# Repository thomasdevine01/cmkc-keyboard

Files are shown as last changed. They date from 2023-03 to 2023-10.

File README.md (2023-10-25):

# Chico State Mechanical Keyboard Club

<p align = "center">
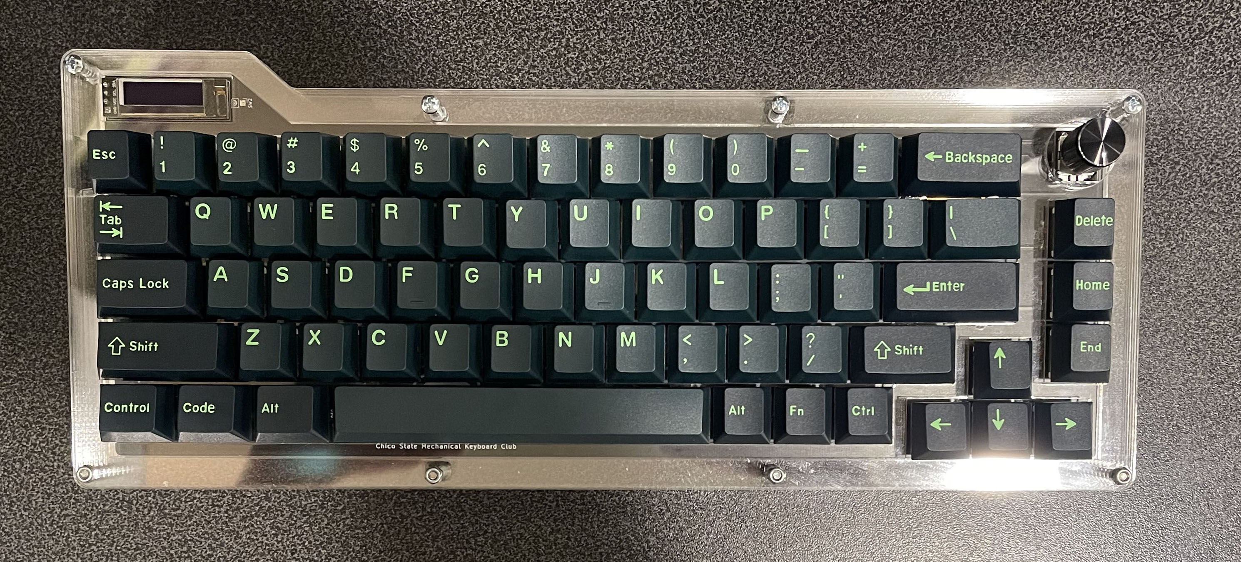
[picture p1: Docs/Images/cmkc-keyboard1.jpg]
    
</p>

<p align = "center">
    A 65% keyboard that features a rotary encoder, OLED Screen and Programmable Firmware.
</p>

## [Installation Guide](Docs/)
  
  1. [Foreword](https://github.com/thomasdevine01/cmkc-keyboard/blob/main/Docs/README.md#foreword)
  2. [Required Parts](https://github.com/thomasdevine01/cmkc-keyboard/blob/main/Docs/README.md#required-parts)
  3. [Optional parts](https://github.com/thomasdevine01/cmkc-keyboard/blob/main/Docs/README.md#optional-parts)
  4. [Tools](https://github.com/thomasdevine01/cmkc-keyboard/blob/main/Docs/README.md#tools)
  5. [Minimum requirements](https://github.com/thomasdevine01/cmkc-keyboard/blob/main/Docs/README.md#minimum-requirements)
  6. [Quality of Life Improvements](https://github.com/thomasdevine01/cmkc-keyboard/blob/main/Docs/README.md#quality-of-life-improvements)
  7. [PCBs: Quick Review](https://github.com/thomasdevine01/cmkc-keyboard/blob/main/Docs/README.md#pcbs-quick-review)
  8. [Soldering: Quick Review](https://github.com/thomasdevine01/cmkc-keyboard/blob/main/Docs/README.md#soldering-quick-review)
  9. [Soldering Tips](https://github.com/thomasdevine01/cmkc-keyboard/blob/main/Docs/README.md#soldering-tips)
  10. [PCB Assembly Tasks](https://github.com/thomasdevine01/cmkc-keyboard/blob/main/Docs/README.md#pcb-assembly-tasks)
  11. [Diodes](https://github.com/thomasdevine01/cmkc-keyboard/blob/main/Docs/README.md#diodes)
  12. [uC Socket](https://github.com/thomasdevine01/cmkc-keyboard/blob/main/Docs/README.md#uc-socket)
  13. [Hardware Fix - Tying Pin 9 to Pin 4](https://github.com/thomasdevine01/cmkc-keyboard/blob/main/Docs/README.md#hardware-fix---tying-pin-9-to-pin-4)
  14. [Recommended Fix - Top Layer](https://github.com/thomasdevine01/cmkc-keyboard/blob/main/Docs/README.md#recommended-fix---top-layer)
  15. [How I did it - Bottom layer underneath socket](https://github.com/thomasdevine01/cmkc-keyboard/blob/main/Docs/README.md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)
  16. [uC header pins](https://github.com/thomasdevine01/cmkc-keyboard/blob/main/Docs/README.md#uc-header-pins)
  17. [Stabilizers](https://github.com/thomasdevine01/cmkc-keyboard/blob/main/Docs/README.md#stabilizers)
  18. [Assembling Stabilizers](https://github.com/thomasdevine01/cmkc-keyboard/blob/main/Docs/README.md#assembling-stabilizers)
  19. [Switches](https://github.com/thomasdevine01/cmkc-keyboard/blob/main/Docs/README.md#switches)
  20. [OLED](https://github.com/thomasdevine01/cmkc-keyboard/blob/main/Docs/README.md#oled)
  21. [Demultiplexer](https://github.com/thomasdevine01/cmkc-keyboard/blob/main/Docs/README.md#demultiplexer)
  22. [Rotary Encoder](https://github.com/thomasdevine01/cmkc-keyboard/blob/main/Docs/README.md#rotary-encoder)
  23. [Soldering Sanity Check](https://github.com/thomasdevine01/cmkc-keyboard/blob/main/Docs/README.md#soldering-sanity-check)
  
## [Photo Gallery](Docs/Images)
## [Parts](Docs/)
### Credits

- Circuit-Dude
- Thomas Devine 

### [Sources](Docs/Sources/)

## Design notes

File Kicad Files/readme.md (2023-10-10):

These are the Schematic and PCB Layout files for the CMKC-65% keyboard.

The current board revision is the -R1.

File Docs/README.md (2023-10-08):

## CMKC PCB Assembly Guide

### Table of Contents
- If you want to use the Table of Contents for navigating the document - click the hambuger menu on the right hand side
1. [Foreword](https://github.com/thomasdevine01/cmkc-keyboard/blob/main/Docs/README.md#foreword)
2. [Required Parts](https://github.com/thomasdevine01/cmkc-keyboard/blob/main/Docs/README.md#required-parts)
3. [Optional parts](https://github.com/thomasdevine01/cmkc-keyboard/blob/main/Docs/README.md#optional-parts)
4. [Tools](https://github.com/thomasdevine01/cmkc-keyboard/blob/main/Docs/README.md#tools)
5. [Minimum requirements](https://github.com/thomasdevine01/cmkc-keyboard/blob/main/Docs/README.md#minimum-requirements)
6. [Quality of Life Improvements](https://github.com/thomasdevine01/cmkc-keyboard/blob/main/Docs/README.md#quality-of-life-improvements)
7. [PCBs: Quick Review](https://github.com/thomasdevine01/cmkc-keyboard/blob/main/Docs/README.md#pcbs-quick-review)
8. [Soldering: Quick Review](https://github.com/thomasdevine01/cmkc-keyboard/blob/main/Docs/README.md#soldering-quick-review)
9. [Soldering Tips](https://github.com/thomasdevine01/cmkc-keyboard/blob/main/Docs/README.md#soldering-tips)
10. [PCB Assembly Tasks](https://github.com/thomasdevine01/cmkc-keyboard/blob/main/Docs/README.md#pcb-assembly-tasks)
11. [Diodes](https://github.com/thomasdevine01/cmkc-keyboard/blob/main/Docs/README.md#diodes)
12. [uC Socket](https://github.com/thomasdevine01/cmkc-keyboard/blob/main/Docs/README.md#uc-socket)
13. [Hardware Fix - Tying Pin 9 to Pin 4](https://github.com/thomasdevine01/cmkc-keyboard/blob/main/Docs/README.md#hardware-fix---tying-pin-9-to-pin-4)
14. [Recommended Fix - Top Layer](https://github.com/thomasdevine01/cmkc-keyboard/blob/main/Docs/README.md#recommended-fix---top-layer)
15. [How I did it - Bottom layer underneath socket](https://github.com/thomasdevine01/cmkc-keyboard/blob/main/Docs/README.md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)
16. [uC header pins](https://github.com/thomasdevine01/cmkc-keyboard/blob/main/Docs/README.md#uc-header-pins)
17. [Stabilizers](https://github.com/thomasdevine01/cmkc-keyboard/blob/main/Docs/README.md#stabilizers)
18. [Assembling Stabilizers](https://github.com/thomasdevine01/cmkc-keyboard/blob/main/Docs/README.md#assembling-stabilizers)
19. [Switches](https://github.com/thomasdevine01/cmkc-keyboard/blob/main/Docs/README.md#switches)
20. [OLED](https://github.com/thomasdevine01/cmkc-keyboard/blob/main/Docs/README.md#oled)
21. [Demultiplexer](https://github.com/thomasdevine01/cmkc-keyboard/blob/main/Docs/README.md#demultiplexer)
22. [Rotary Encoder](https://github.com/thomasdevine01/cmkc-keyboard/blob/main/Docs/README.md#rotary-encoder)
23. [Soldering Sanity Check](https://github.com/thomasdevine01/cmkc-keyboard/blob/main/Docs/README.md#soldering-sanity-check)

### Foreword

This document is meant to serve as a how-to guide for assembling the CMKC PCB. At the time of writing, the first revision of the PCB design has a hardware error that we will need to correct during assembly.

All source documentation can be found: [https://github.com/thomasdevine01/cmkc\_pcb](https://github.com/thomasdevine01/cmkc_pcb)

### Required Parts

- 1 - PCB
- 67 - MX Cherry style switches
- 1 - Stabilizer Kit - [60 Kit](https://www.amazon.com/DUROCK-Stabilizers-Translucent-Keyboard-Mechanical/dp/B0B2RVN19F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)
- 67 - Through Hole 1N4148 Diodes
- 1 - Acrylic case switch pate
- 1 - Nice!-Nano uC
  - [Manufacturer Listed Distributors](https://nicekeyboards.com/nice-nano#find-a-store)
- 1 - CD74HC4514 Demultiplexer
  - Manufacturer's website: [https://www.ti.com/product/CD74HC4514](https://www.ti.com/product/CD74HC4514)
  - Verified Distributors: [Digikey](https://www.digikey.com/en/products/detail/texas-instruments/CD74HC4514M96/1507316), [Arrow](https://www.arrow.com/en/products/cd74hc4514m96/texas-instruments), [Mouser](https://www.mouser.com/ProductDetail/Texas-Instruments/CD74HC4514M96?qs=xFfolx0DHx3s6ILXGQ%2FrLQ%3D%3D)
- 1 inch 30 AWG wire

### Optional parts

- SSD1306 128x32 pixel OLED Display
  - Must be set up for I2C communication
- Rotary Encoder
  - With or without push button
- 24 Mill-Max [header pins](https://keebd.com/en-us/products/mill-max-low-profile-controller-pins-pack-of-25)
- Female socket

### Tools
#### Minimum requirements
- Soldering Iron
- Sponge 
  - Water to wet the sponge
- Steel wool pad
- At least one tube of solder 
- Room with a window
- Tweezers 
- Patience 
- Solder wick / solder sucker
- Wire cutters
- Flush cuts preferred

#### Quality of Life Improvements
- Adjustable lamp for additional lighting
- Fan to exhaust soldering fumes
- Flux 
- Thin / Precision tweezers
- Steady hands
- Thin / Pencil soldering iron tip for SMD portion

### PCBs: Quick Review

PCB is a three letter acronym standing for "Printed Circuit Board". PCBs are a convenient and efficient way to connect devices and create physical circuits. PCBs can have multiple layers, allowing for complex layouts. The CMKC PCB is a two layer PCB, example below:

<p align = "left">
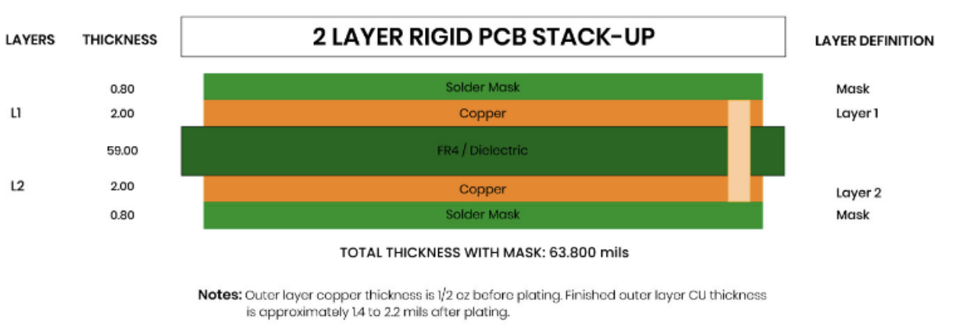
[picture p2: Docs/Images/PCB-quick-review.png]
    
</p>

Essentially, copper is sandwiched between layers of a dielectric material and then "etched" to remove copper where we don't want connections and masked to leave copper where we want connections. Solder mask is applied to the outer layers so that copper is exposed only on device "pads" or places we want exposed for probing, test points, etc. Vias connect copper on different layers.

The CMKC PCB was designed using KiCAD, a free, opensource, CAD software. It is recommended to view the schematic and PCB layout when trying to figure out how things are connected.

### Soldering: Quick Review

Soldering is the process of electrically connecting two (or more) pieces of metal with a low melting point alloy. The alloy used is what is known as "solder" (pronounced "Saw-Der").

There are two main types of technologies that describe how parts connect to PCBs: through hole (THT) and Surface Mount (SMD , SMT). 99% of the parts used on the CMKC PCB are through hole, there is ONE SMD that we will need to solder down in order to make our Keyboard work.

GreatScott!, on Youtube has a great soldering tutorial
[https://www.youtube.com/watch?v=VxMV6wGS3NY](https://www.youtube.com/watch?v=VxMV6wGS3NY)

## Soldering Tips

- Be mindful of how hot your soldering iron is. You need your iron to be hot enough to melt whatever solder you use, but there is such a thing as "too hot" of an iron. Particular care should be taken when soldering the Demultiplexer and the header pins on the Nice!-nano and OLED display. These devices have sensitive electronics on them and exposing them to too much heat can damage the devices.

- Be mindful of how long you hold your iron on a given pad, ~3-5 seconds should be long enough to melt the solder and make the connection. As the copper heats up, so does the FR4 substrate holding the copper in place. It is possible to melt this substrate and detach pads from the PCB, making them very susceptible to ripping.

- Try not to breathe the smoke or get it in your eyes. It is not uncommon to get leaded solder from your local hardware store. Regardless of lead content: the chemicals in solder are toxic and should not be ingested. The smoke irritates eyes and sinuses and doesn't feel good.

### PCB Assembly Tasks

#### Diodes

Soldering the diodes is probably the easiest task. We're first going to want to bend the legs of the diodes so that they're roughly spaced like the pads on the PCB.

<p align = "left">
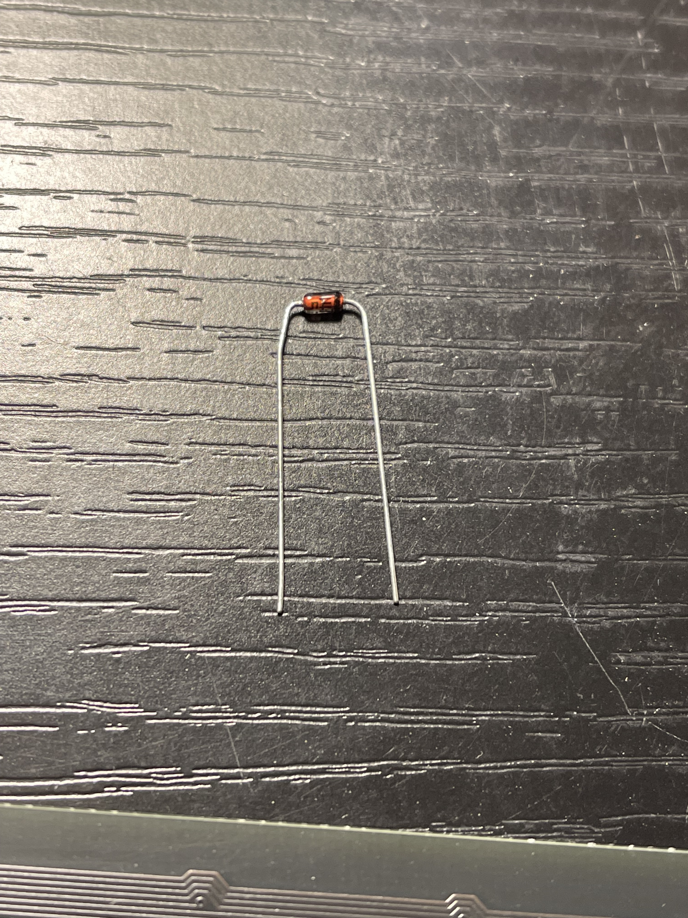
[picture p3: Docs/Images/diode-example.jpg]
    
</p>

We're then going to put the legs of the diodes through the pads on the board.

**NOTE:** The orientation of the diode is such that the black line seen on the body of the diode matches the line on the silkscreen of the PCB. The line of the body / silkscreen resembles the cathode of the diode.

With the diode in place, I like to bend the legs so that it stays in place and I can "rinse and repeat" for the remaining diodes

<p align = "left">
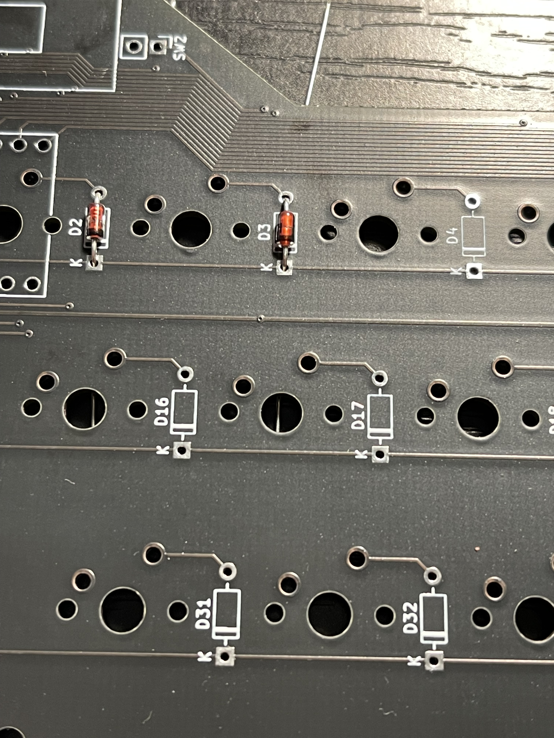
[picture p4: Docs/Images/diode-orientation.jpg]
    
</p>

<p align = "left">
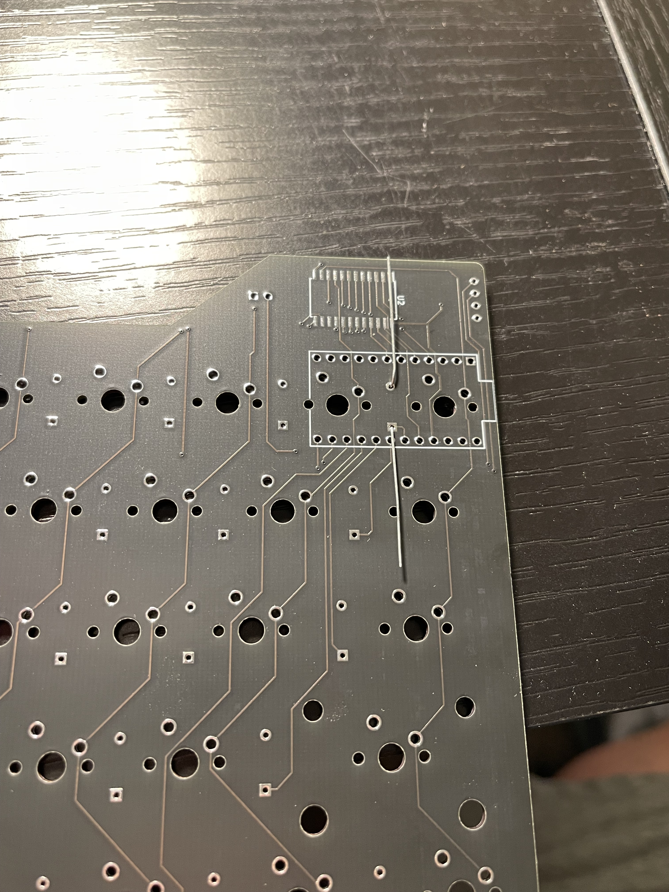
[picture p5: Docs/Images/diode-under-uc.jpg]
    
</p>

After we put all the diodes in their pads, solder them, and clip the excess.

**NOTE:** You can save the diode leg clippings and use them as socket male header pins for the uC

<p align = "left">
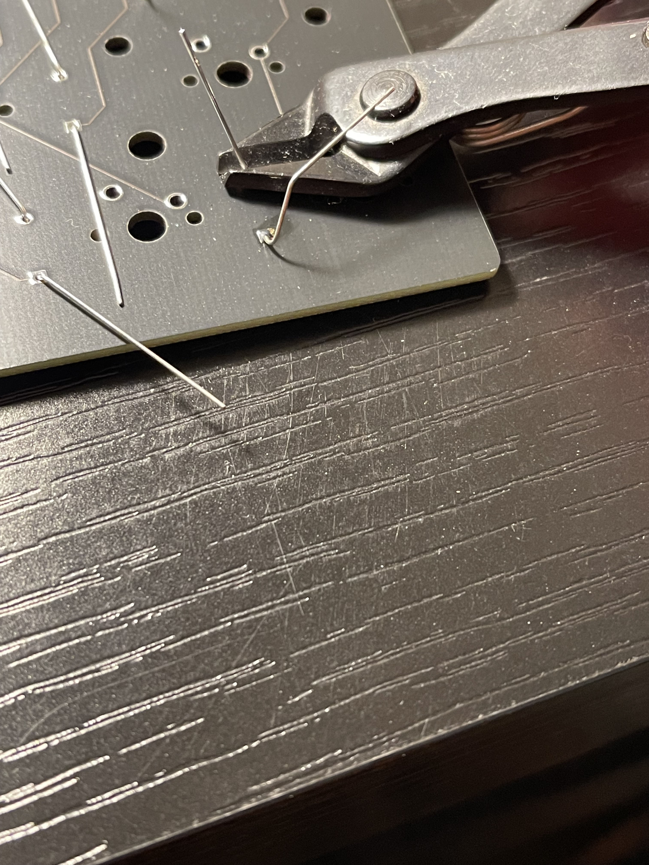
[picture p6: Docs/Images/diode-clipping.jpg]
    
</p>

<p align = "left">
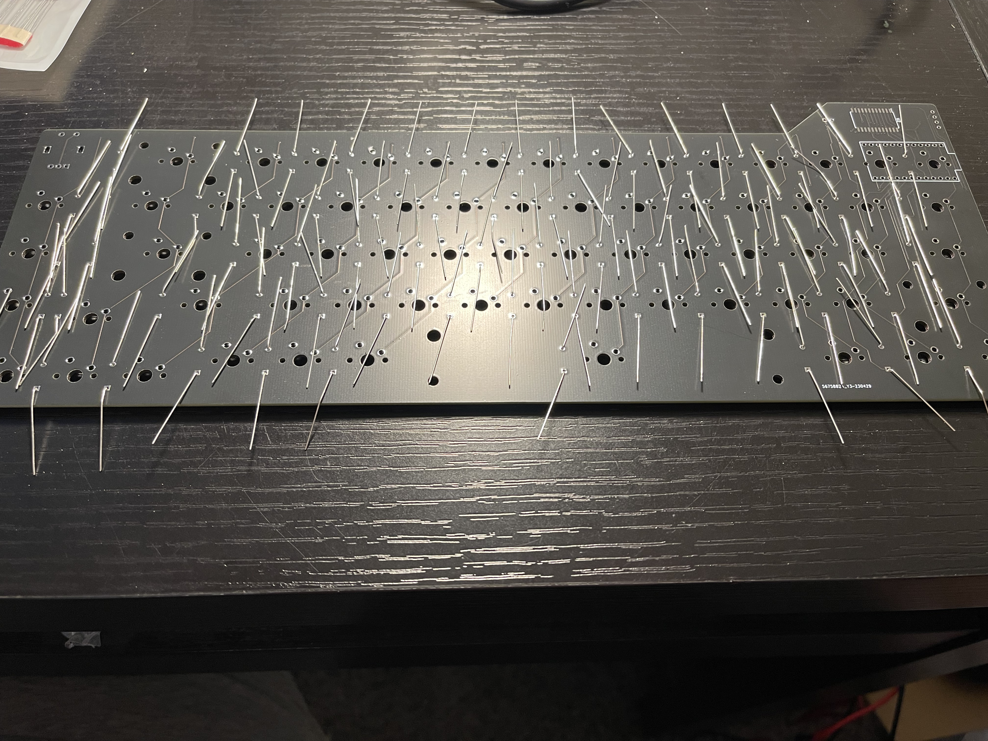
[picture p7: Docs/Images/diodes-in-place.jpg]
    
</p>

You've now put all your diodes on the board

## uC Socket

The uC socket is pretty straight forward. We're going to place the socket pins through the pads from the bottom side of the board. 

In order to ensure that the socket doesn't fall off before we get a chance to solder it to the board, I like to use tape to hold the part in place until we solder at least one pin.

Line up the socket so that it's as straight vertically as possible and use tape to hold the socket in place.

<p align = "left">
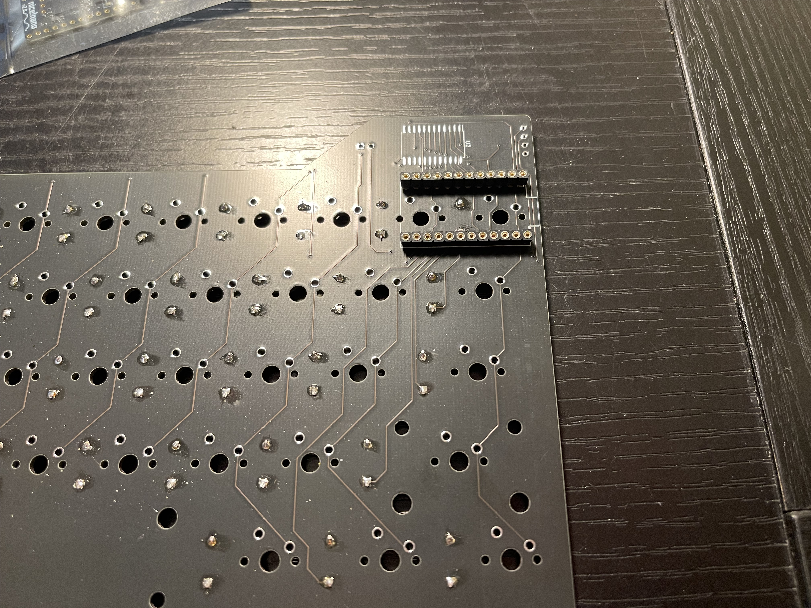
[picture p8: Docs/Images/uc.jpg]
    
</p>
<p align = "left">
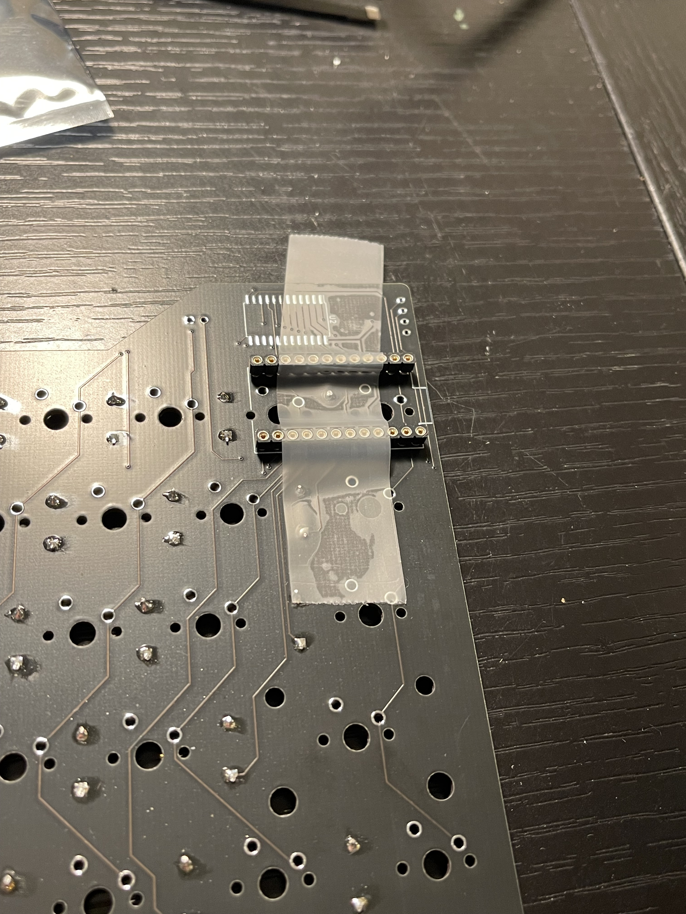
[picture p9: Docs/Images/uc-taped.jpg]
    
</p>

###

Solder the pins from the top side of the board.

<p align = "left">
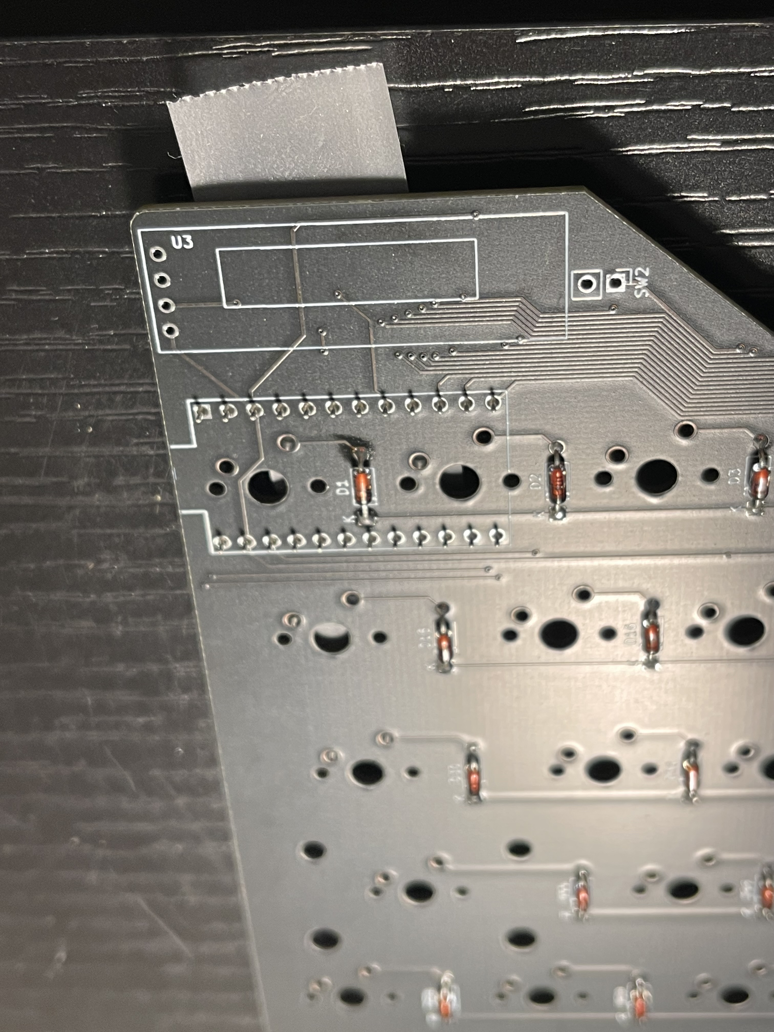
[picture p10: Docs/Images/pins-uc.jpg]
    
</p>

You'll notice that the socket pins get pretty close to where the first two switches mount onto the board. To avoid possible fitment issues, we're going to clip pins 24 and 20 from the top side.

<p align = "left">
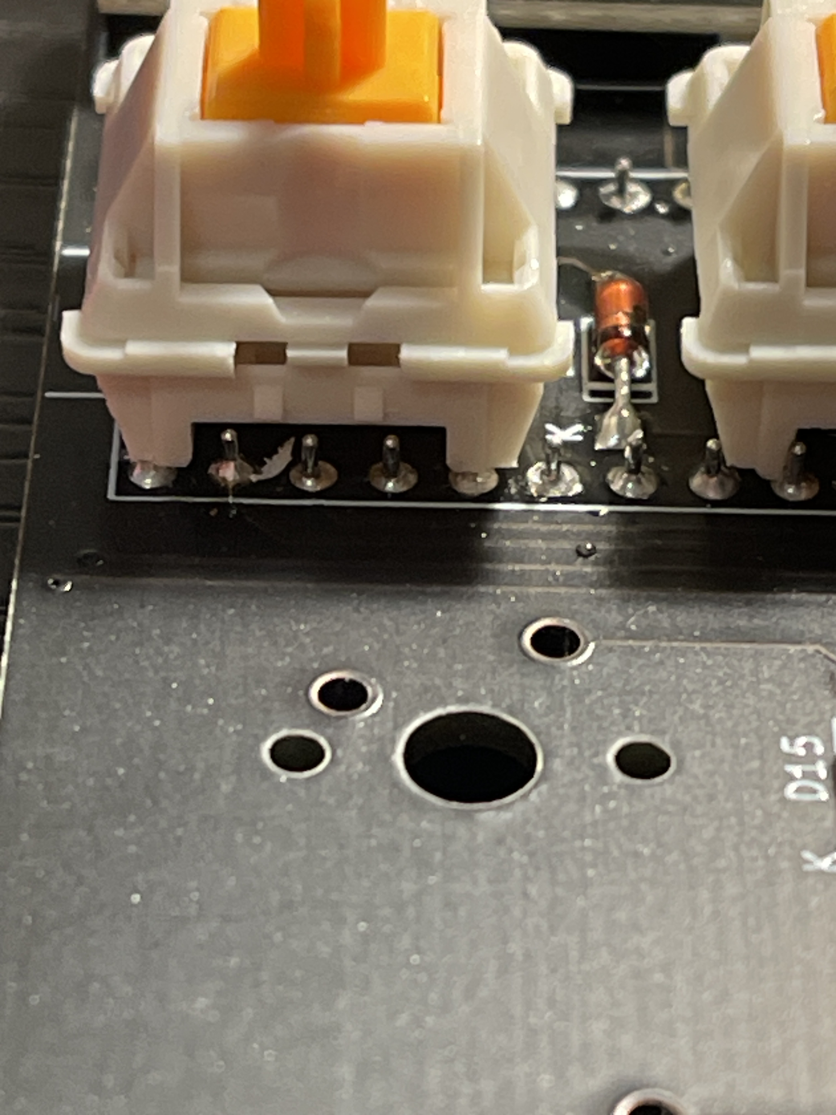
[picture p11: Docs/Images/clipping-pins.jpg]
    
</p>

### Hardware Fix - Tying Pin 9 to Pin 4

On the schematic I didn't catch that our CLD1 pin is tied to pin 4 on the uC, which is a ground pin (shoutout to @Josh\_little  for catching this error.) Luckily, this is a pretty easy fix. I can't show pictures of how I would recommend fixing this, because by the time this issue was found, I had already mounted the switches and the acrylic was covering where I needed to solder. Below is the pin numbering scheme for reference

<p align = "left">
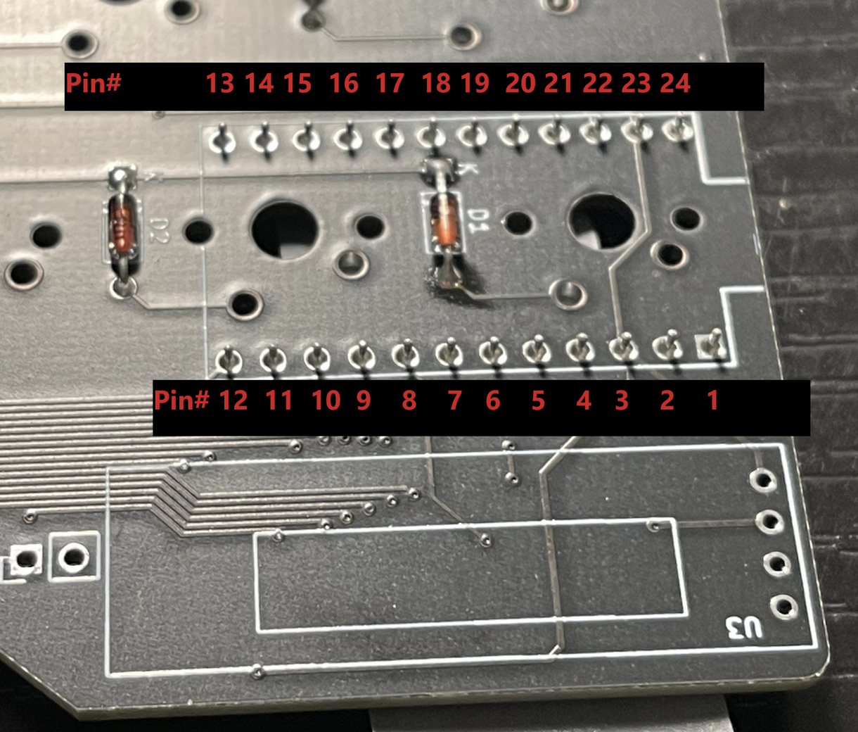
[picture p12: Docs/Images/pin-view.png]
    
</p>

#### Recommended Fix - Top Layer

You'll need to solder a piece of wire that connects pin 4 to pin 9 on the top side of the board. The consequence is that this will be visible through the acrylic, so you'll want to do as clean of a job as you can.

<p align = "left">
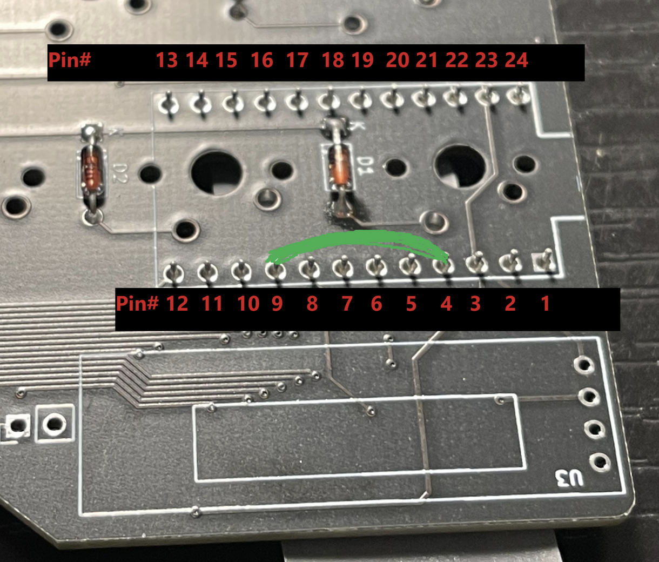
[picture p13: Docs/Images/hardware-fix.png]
    
</p>

#### How I did it - Bottom layer underneath socket

I was forced to do the fix this way but I do not recommend doing this if you're new to soldering. You'll notice in the picture that I burned the plastic of the socket. It's not very easy. I took a piece of 30AWG wire ~ 1 inch long and stripped one end so that a little piece of wire was exposed. I tacked that end to pin 4. I then put solder on my tip, held the wire close to pin 9 and burned through the insulation until a solder connection was made. You must be careful not to have too much solder and short and pins together. I then wiggled the excess wire lightly until it snapped off

<p align = "left">
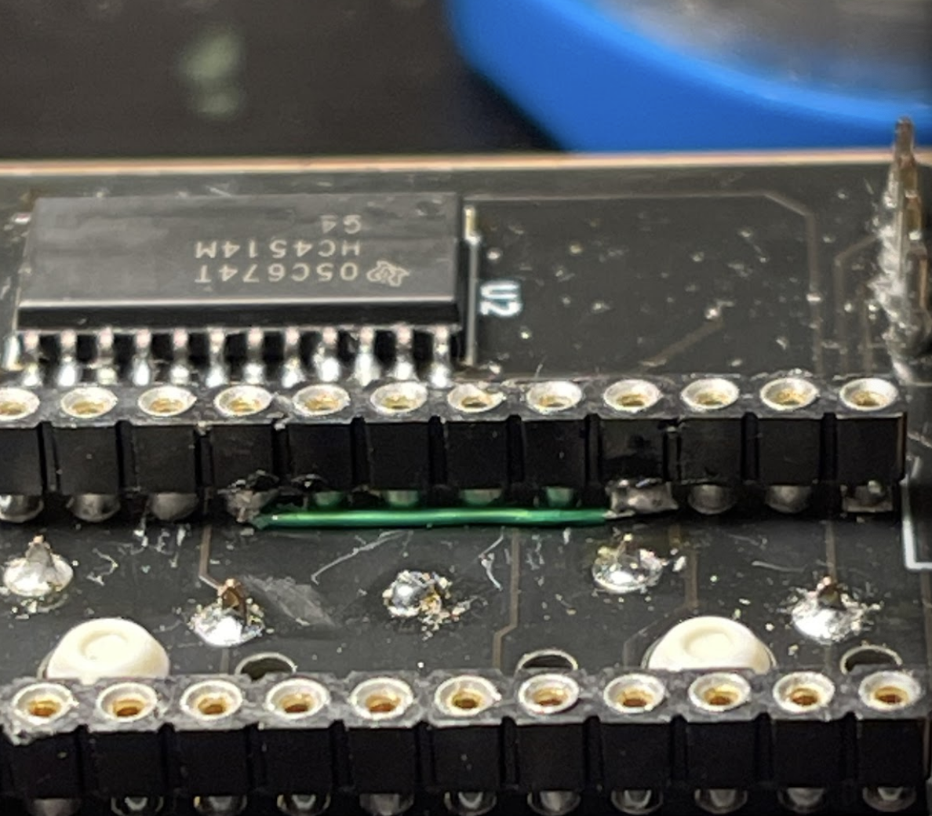
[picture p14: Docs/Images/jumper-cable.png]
    
</p>

## uC header pins

With the socket soldered in, I put the mill-max machine header pins into the sockets. You want the pins decently in the sockets, this will be how the uC is mounted at the conclusion of this step.

**NOTE:** DO NOT POPULATE PIN 4. THAT WILL UNDO THE HARDWARE FIX DESCRIBED ABOVE. The pictures below will show pin 4 being populated,after the bug was found the pin was removed but the pictures had already been taken and I only had one board to assemble to show these steps. This is also where you could use diode legs if you don't have the Mill-Max header pins.

<p align = "left">
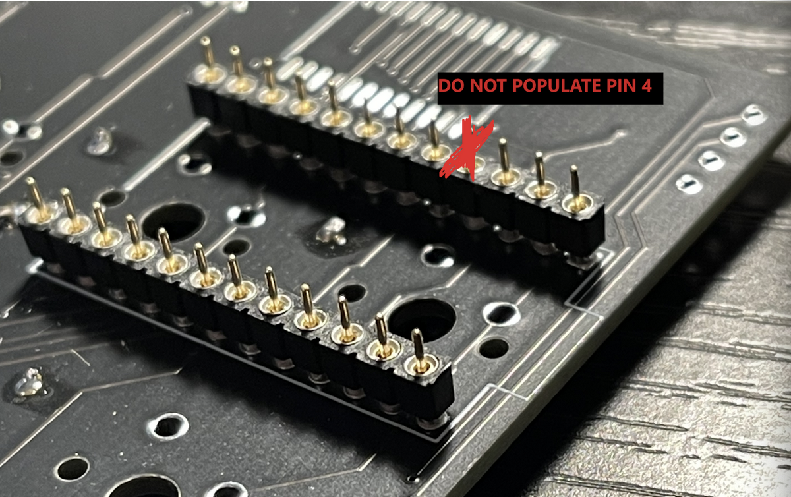
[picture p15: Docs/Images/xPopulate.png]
    
</p>

Next place your uC onto the pins

<p align = "left">
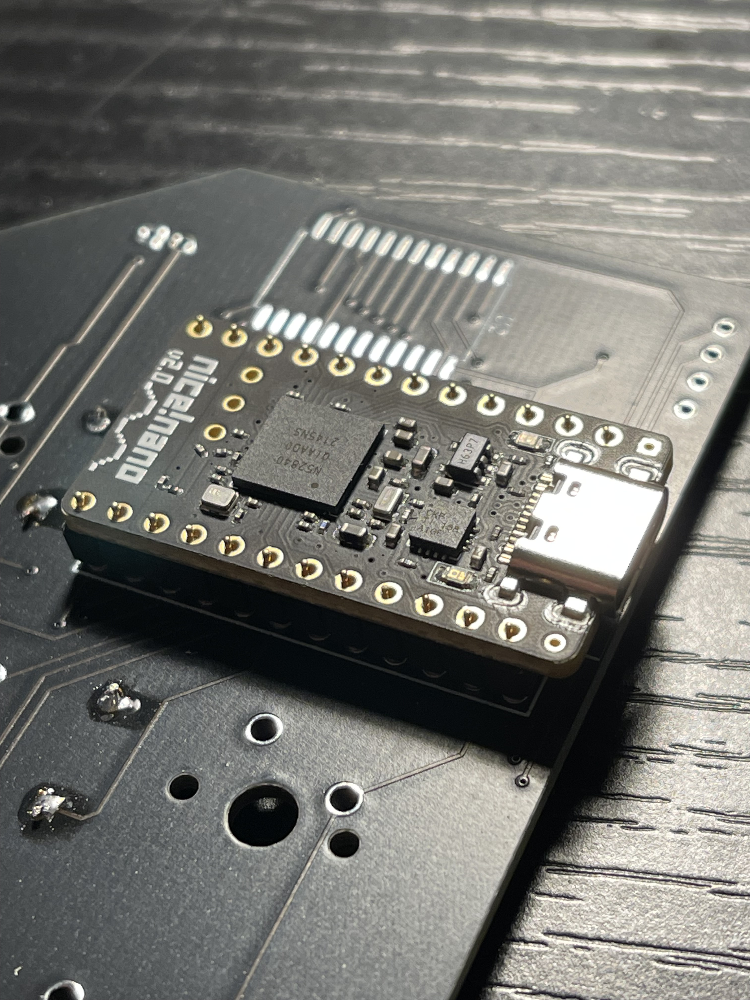
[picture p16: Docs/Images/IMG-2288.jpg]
    
</p>

Solder the pins to the uC. Try not to use so much solder such that you end up soldering the uC to the socket .

<p align = "left">
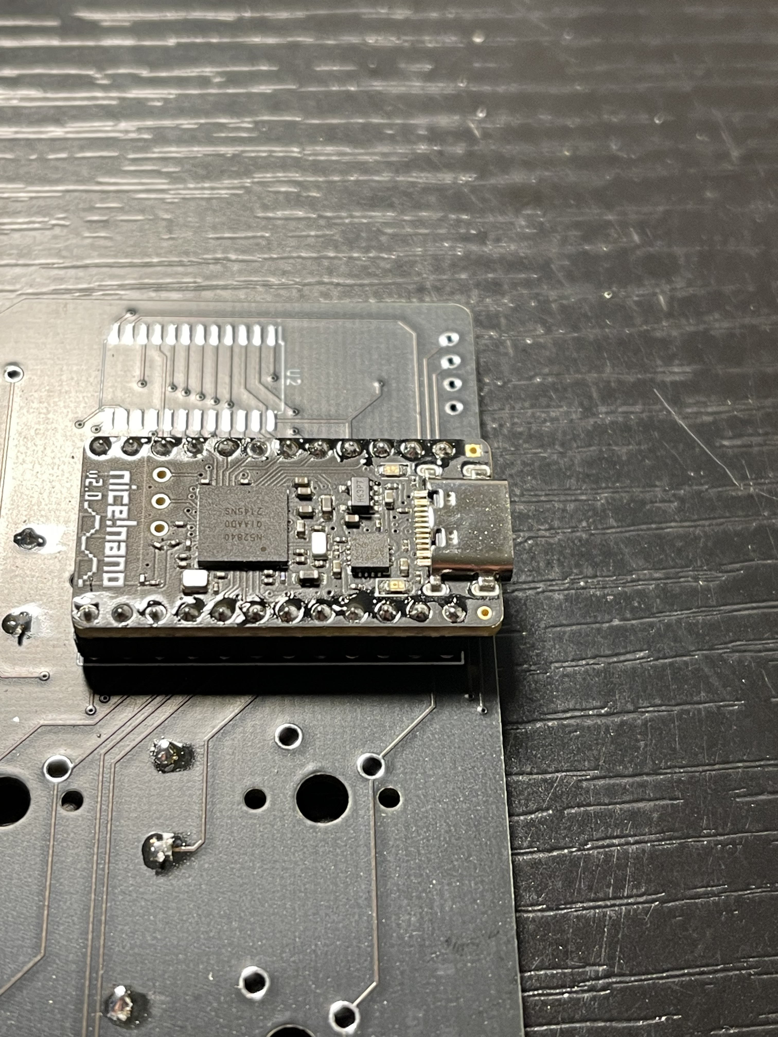
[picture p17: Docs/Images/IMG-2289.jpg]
    
</p>

Once cooled, you can now remove and replace your uC during debug / assembly.

##

## Stabilizers

The stabilizers need to clip into the switch plate before you begin soldering the switches. Whether you decide to go with screw in or clip in - The keyboard supports both options so that is possible. This cannot be stressed enough, if you have screw in stabilizers and plate mount switches: the stabilizers mount to the PCB and **MUST BE INSTALLED FIRST BEFORE ANY SWITCHES.**

### Assembling Stabilizers

This is a fairly straightforward process, There are three major components to stabilizers: housing, stem, and wire. Assemble the housing, insert the stem into the housing from the bottom, and then feed the wire between the housing and the stem.

NOTE: There is a sweet spot here, it may take a couple of attempts to get it right, just pop the wire from the housing and retry.

<p align = "left">
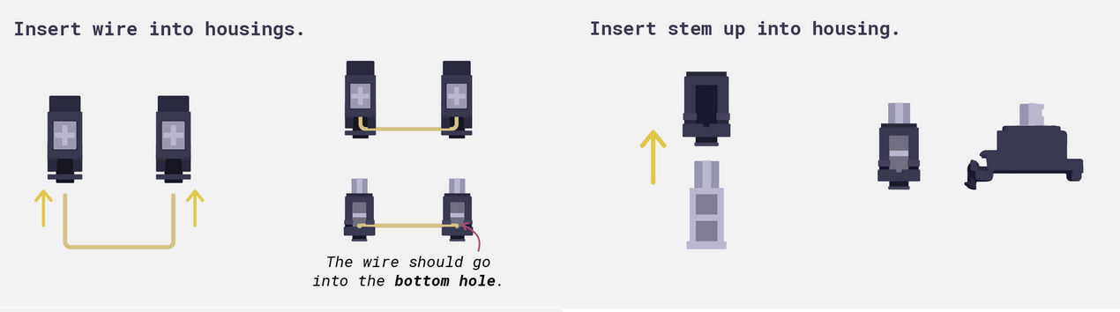
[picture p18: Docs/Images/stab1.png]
    
</p>

<p align = "left">
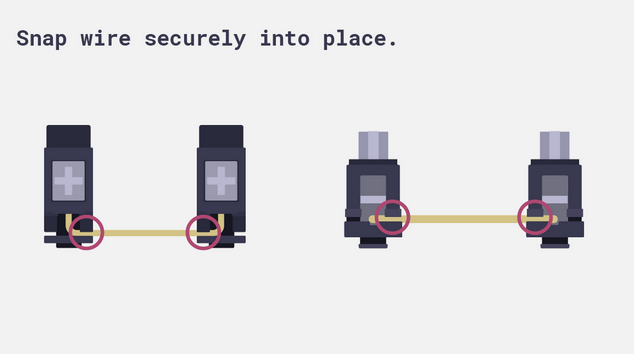
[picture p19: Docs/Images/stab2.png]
    
</p>

Side Note: It is common for people to modify their stabilizers. There are two common mods you can do. The first is clipping the stems. On the bottom of the stem there is an excess of plastic, clip them and you're good. The second modification is lube, apply lube to the inside of the housing and the stem where there is motion. On the bent ends of the wire, it's common for people to apply heavy lube or a type of lube called "dielectric grease", it is not necessary but does make a difference. There are endless mods to stabilizers, check out the assembly [source](https://www.keyboard.university/guides/using-screw-in-stabilizers-7nxj6) as well as a clipping [tutorial](https://switchandclick.com/how-to-mod-your-stabilizers-band-aid-clip-and-lube/).

## Switches

Note: the following pictures do not show stabilizers. This is because circuit-dude didn't realize he needed them. He installed all of his switches, bought PCB mount stabilizers after the fact, and then had to un-solder all 67 switches in order to install the stabilizers. Don't be like circuit-dude.

The switches can be a challenge while you're getting the first couple in. I found that putting in 3 switches in a triangular pattern helped keep everything relatively where it needed to be.

You're going to place the switches through the holes in the acrylic and then solder the switch to the board. Note that you need to take off the acrylic wrap prior to doing this.

<p align = "left">
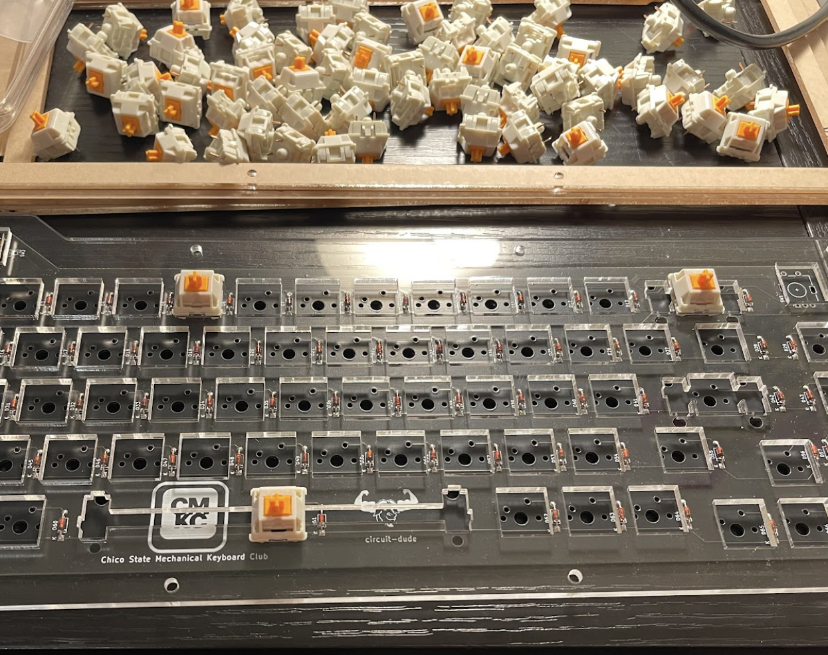
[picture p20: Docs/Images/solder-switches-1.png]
    
</p>

You want the switches to sit as flush as possible to the acrylic.

<p align = "left">
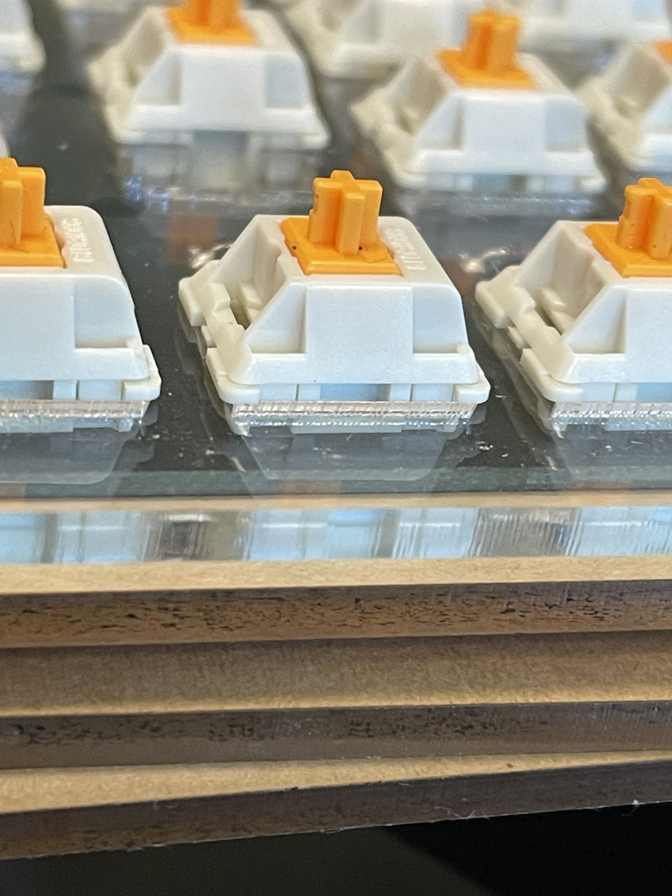
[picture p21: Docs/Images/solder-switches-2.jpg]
    
</p>

Fill in all the holes, solder in all the switches, and bloom blam bow you damn near got a keyboard brother.

## OLED

The OLED is pretty straight forward. Solder the header pins through the holes and then onto the board. It only fits one way. Just remember to be conscious of the heat and not fry the OLED.

<p align = "left">
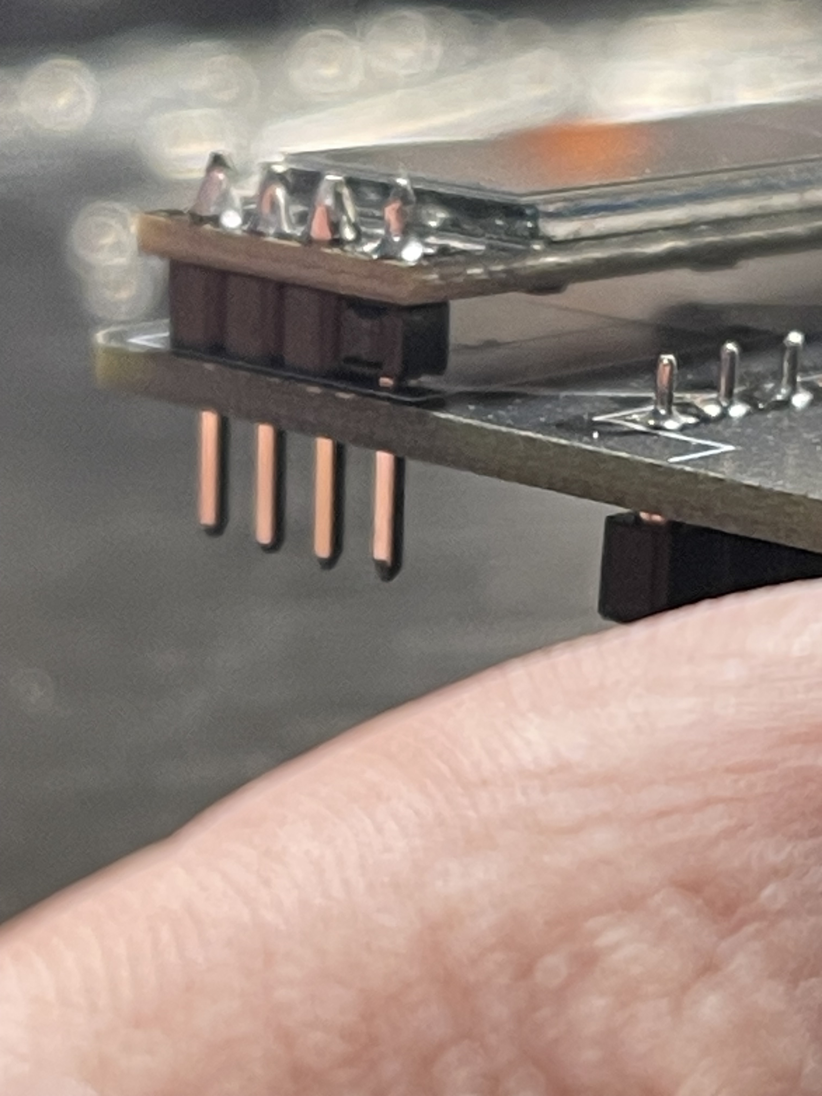
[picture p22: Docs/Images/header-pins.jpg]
    
</p>

## Demultiplexer

The demultiplexer is the only SMD part on this board. It is a little challenging due to the pin pitch but it's doable. You do need to be careful not to heat up the pads too much so that they don't delaminate and rip off the board.

I'd start with "tinning" one pad (i.e. add solder to one pad on one corner).

<p align = "left">
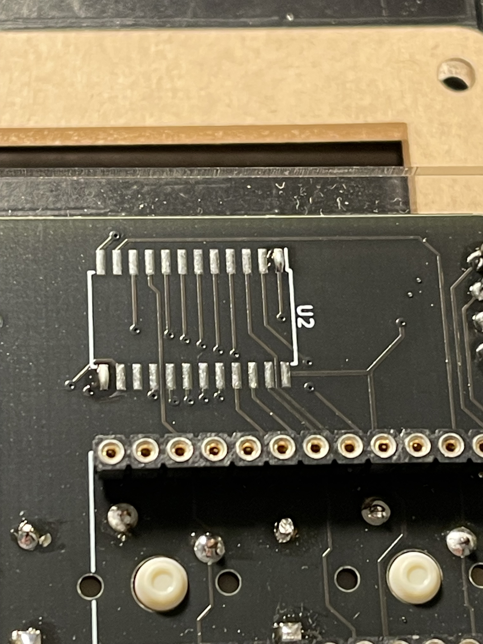
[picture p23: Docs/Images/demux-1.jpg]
    
</p>

With a corner tinned, use some tweezers to grab the IC. Prepare to move the IC onto that pad. We're going to melt the solder on the pad you just tinned and line up all the pins with their respective pads. You can melt the solder a couple of times if you don't get it right on the first shot.

**NOTE:** The long line on the silkscreen indicates Pin 1's position. Pin one is marked with the dot on the package of the IC.

<p align = "left">
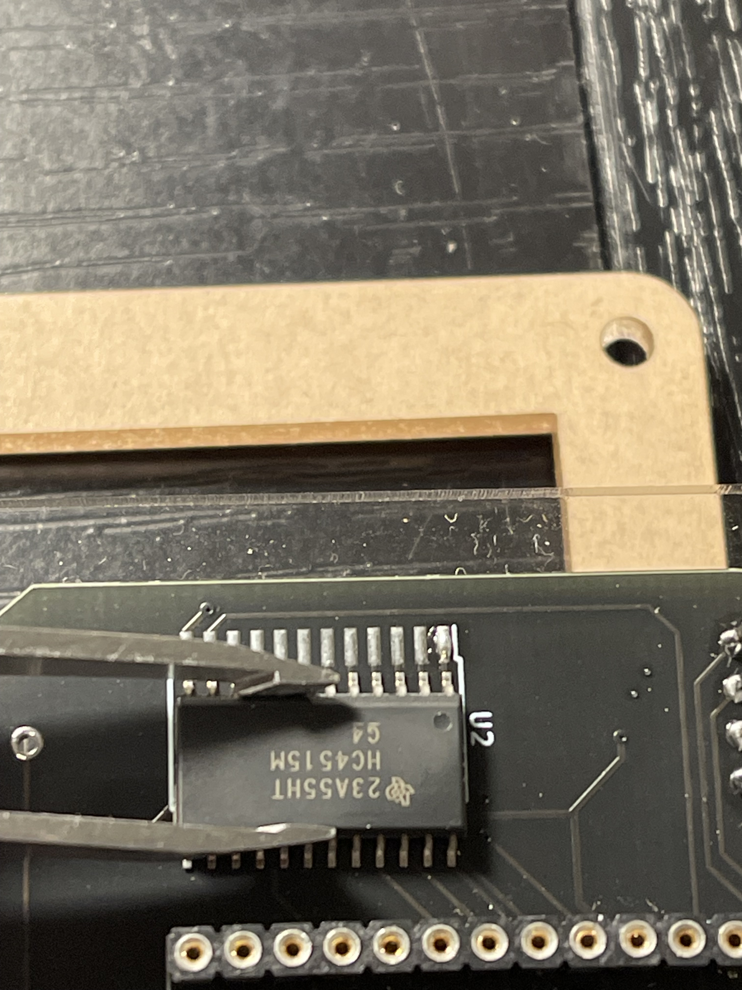
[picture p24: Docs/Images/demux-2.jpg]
    
</p>

<p align = "left">
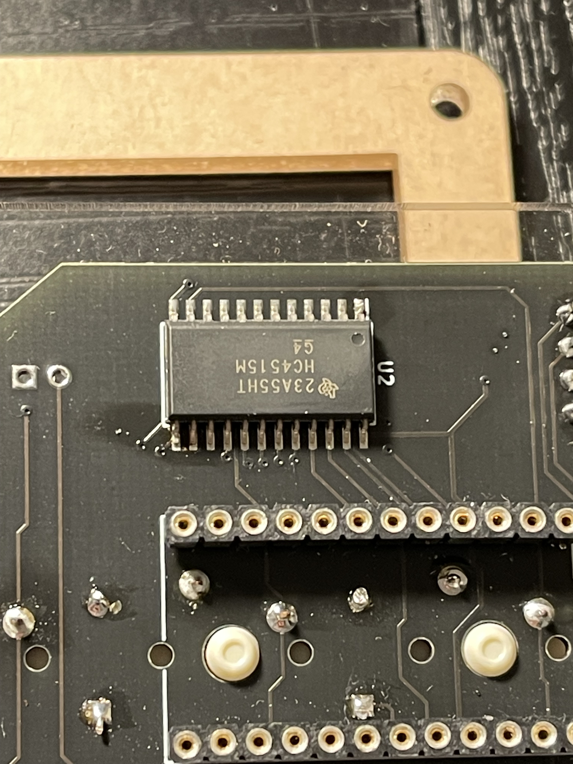
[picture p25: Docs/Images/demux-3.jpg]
    
</p>

With one corner tacked down and all the pins lined up, I like to tack a pin on the opposite corner. This makes it so the part doesn't move around while you solder the next couple pins.

<p align = "left">
    
</p>

Note the massive solder blob in the picture above. I'd recommend cleaning that up to avoid shorting pins while soldering the pins immediately to the right.

Proceed to solder the rest of the pins in whatever way you feel comfortable.

## Rotary Encoder

```diff
- I would put the rotary encoder on last because of its height.
```

The rotary encoder is pretty straight forward. Put the pins through the holes, solder the pins to the pads, bada-bing you've got a rotary encoder knob on your board. I don't have any images of installing this :'(

VOILA, you've assembled your keyboard!.

###

### Soldering Sanity Check

There is a simple program in Firmware/PCB\_sanity\_check.py that will set up all the pins associated with the matrix and then indefinitely scan the matrix and tell you which buttons were registered as pressed. You can run this code after you install circuit-python and make sure that all of your switches register when you depress them. If they don't, things to check would be:

- Demultiplexer soldering
- Switch soldering
- Socket soldering
  - Ensure that pin 4 is not populated on the uC
  - Check that pin 4 of the socket is connected to pin 9 of the socket
  - Socket connections to PCB
- Burnt traces / ripped pads
  - This would kinda suck but is fixable, it would require soldering wires from the disconnected part(s) to somewhere else that on the net that is connected.

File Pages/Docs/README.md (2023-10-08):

## CMKC PCB Assembly Guide

### Table of Contents
- If you want to use the Table of Contents for navigating the document - click the hambuger menu on the right hand side
1. [Foreword](https://github.com/thomasdevine01/cmkc-keyboard/blob/main/Docs/README.md#foreword)
2. [Required Parts](https://github.com/thomasdevine01/cmkc-keyboard/blob/main/Docs/README.md#required-parts)
3. [Optional parts](https://github.com/thomasdevine01/cmkc-keyboard/blob/main/Docs/README.md#optional-parts)
4. [Tools](https://github.com/thomasdevine01/cmkc-keyboard/blob/main/Docs/README.md#tools)
5. [Minimum requirements](https://github.com/thomasdevine01/cmkc-keyboard/blob/main/Docs/README.md#minimum-requirements)
6. [Quality of Life Improvements](https://github.com/thomasdevine01/cmkc-keyboard/blob/main/Docs/README.md#quality-of-life-improvements)
7. [PCBs: Quick Review](https://github.com/thomasdevine01/cmkc-keyboard/blob/main/Docs/README.md#pcbs-quick-review)
8. [Soldering: Quick Review](https://github.com/thomasdevine01/cmkc-keyboard/blob/main/Docs/README.md#soldering-quick-review)
9. [Soldering Tips](https://github.com/thomasdevine01/cmkc-keyboard/blob/main/Docs/README.md#soldering-tips)
10. [PCB Assembly Tasks](https://github.com/thomasdevine01/cmkc-keyboard/blob/main/Docs/README.md#pcb-assembly-tasks)
11. [Diodes](https://github.com/thomasdevine01/cmkc-keyboard/blob/main/Docs/README.md#diodes)
12. [uC Socket](https://github.com/thomasdevine01/cmkc-keyboard/blob/main/Docs/README.md#uc-socket)
13. [Hardware Fix - Tying Pin 9 to Pin 4](https://github.com/thomasdevine01/cmkc-keyboard/blob/main/Docs/README.md#hardware-fix---tying-pin-9-to-pin-4)
14. [Recommended Fix - Top Layer](https://github.com/thomasdevine01/cmkc-keyboard/blob/main/Docs/README.md#recommended-fix---top-layer)
15. [How I did it - Bottom layer underneath socket](https://github.com/thomasdevine01/cmkc-keyboard/blob/main/Docs/README.md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)
16. [uC header pins](https://github.com/thomasdevine01/cmkc-keyboard/blob/main/Docs/README.md#uc-header-pins)
17. [Stabilizers](https://github.com/thomasdevine01/cmkc-keyboard/blob/main/Docs/README.md#stabilizers)
18. [Assembling Stabilizers](https://github.com/thomasdevine01/cmkc-keyboard/blob/main/Docs/README.md#assembling-stabilizers)
19. [Switches](https://github.com/thomasdevine01/cmkc-keyboard/blob/main/Docs/README.md#switches)
20. [OLED](https://github.com/thomasdevine01/cmkc-keyboard/blob/main/Docs/README.md#oled)
21. [Demultiplexer](https://github.com/thomasdevine01/cmkc-keyboard/blob/main/Docs/README.md#demultiplexer)
22. [Rotary Encoder](https://github.com/thomasdevine01/cmkc-keyboard/blob/main/Docs/README.md#rotary-encoder)
23. [Soldering Sanity Check](https://github.com/thomasdevine01/cmkc-keyboard/blob/main/Docs/README.md#soldering-sanity-check)

### Foreword

This document is meant to serve as a how-to guide for assembling the CMKC PCB. At the time of writing, the first revision of the PCB design has a hardware error that we will need to correct during assembly.

All source documentation can be found: [https://github.com/thomasdevine01/cmkc\_pcb](https://github.com/thomasdevine01/cmkc_pcb)

### Required Parts

- 1 - PCB
- 67 - MX Cherry style switches
- 1 - Stabilizer Kit - [60 Kit](https://www.amazon.com/DUROCK-Stabilizers-Translucent-Keyboard-Mechanical/dp/B0B2RVN19F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)
- 67 - Through Hole 1N4148 Diodes
- 1 - Acrylic case switch pate
- 1 - Nice!-Nano uC
  - [Manufacturer Listed Distributors](https://nicekeyboards.com/nice-nano#find-a-store)
- 1 - CD74HC4514 Demultiplexer
  - Manufacturer's website: [https://www.ti.com/product/CD74HC4514](https://www.ti.com/product/CD74HC4514)
  - Verified Distributors: [Digikey](https://www.digikey.com/en/products/detail/texas-instruments/CD74HC4514M96/1507316), [Arrow](https://www.arrow.com/en/products/cd74hc4514m96/texas-instruments), [Mouser](https://www.mouser.com/ProductDetail/Texas-Instruments/CD74HC4514M96?qs=xFfolx0DHx3s6ILXGQ%2FrLQ%3D%3D)
- 1 inch 30 AWG wire

### Optional parts

- SSD1306 128x32 pixel OLED Display
  - Must be set up for I2C communication
- Rotary Encoder
  - With or without push button
- 24 Mill-Max [header pins](https://keebd.com/en-us/products/mill-max-low-profile-controller-pins-pack-of-25)
- Female socket

### Tools
#### Minimum requirements
- Soldering Iron
- Sponge 
  - Water to wet the sponge
- Steel wool pad
- At least one tube of solder 
- Room with a window
- Tweezers 
- Patience 
- Solder wick / solder sucker
- Wire cutters
- Flush cuts preferred

#### Quality of Life Improvements
- Adjustable lamp for additional lighting
- Fan to exhaust soldering fumes
- Flux 
- Thin / Precision tweezers
- Steady hands
- Thin / Pencil soldering iron tip for SMD portion

## Minimum requirements

- Soldering Iron
- Sponge
  - Water to wet the sponge
- Steel wool pad
- At least one tube of solder
- Room with a window
- Tweezers
- Patience
- Solder wick / solder sucker
- Wire cutters
  - Flush cuts preferred

## Quality of Life Improvements

- Adjustable lamp for additional lighting
- Fan to exhaust soldering fumes
- Flux
- Thin / Precision tweezers
- Steady hands
- Thin / Pencil soldering iron tip for SMD portion

### PCBs: Quick Review

PCB is a three letter acronym standing for "Printed Circuit Board". PCBs are a convenient and efficient way to connect devices and create physical circuits. PCBs can have multiple layers, allowing for complex layouts. The CMKC PCB is a two layer PCB, example below:

<p align = "left">
    
</p>

Essentially, copper is sandwiched between layers of a dielectric material and then "etched" to remove copper where we don't want connections and masked to leave copper where we want connections. Solder mask is applied to the outer layers so that copper is exposed only on device "pads" or places we want exposed for probing, test points, etc. Vias connect copper on different layers.

The CMKC PCB was designed using KiCAD, a free, opensource, CAD software. It is recommended to view the schematic and PCB layout when trying to figure out how things are connected.

### Soldering: Quick Review

Soldering is the process of electrically connecting two (or more) pieces of metal with a low melting point alloy. The alloy used is what is known as "solder" (pronounced "Saw-Der").

There are two main types of technologies that describe how parts connect to PCBs: through hole (THT) and Surface Mount (SMD , SMT). 99% of the parts used on the CMKC PCB are through hole, there is ONE SMD that we will need to solder down in order to make our Keyboard work.

GreatScott!, on Youtube has a great soldering tutorial
[https://www.youtube.com/watch?v=VxMV6wGS3NY](https://www.youtube.com/watch?v=VxMV6wGS3NY)

## Soldering Tips

- Be mindful of how hot your soldering iron is. You need your iron to be hot enough to melt whatever solder you use, but there is such a thing as "too hot" of an iron. Particular care should be taken when soldering the Demultiplexer and the header pins on the Nice!-nano and OLED display. These devices have sensitive electronics on them and exposing them to too much heat can damage the devices.

- Be mindful of how long you hold your iron on a given pad, ~3-5 seconds should be long enough to melt the solder and make the connection. As the copper heats up, so does the FR4 substrate holding the copper in place. It is possible to melt this substrate and detach pads from the PCB, making them very susceptible to ripping.

- Try not to breathe the smoke or get it in your eyes. It is not uncommon to get leaded solder from your local hardware store. Regardless of lead content: the chemicals in solder are toxic and should not be ingested. The smoke irritates eyes and sinuses and doesn't feel good.

### PCB Assembly Tasks

#### Diodes

Soldering the diodes is probably the easiest task. We're first going to want to bend the legs of the diodes so that they're roughly spaced like the pads on the PCB.

<p align = "left">
    
</p>

We're then going to put the legs of the diodes through the pads on the board.

**NOTE:** The orientation of the diode is such that the black line seen on the body of the diode matches the line on the silkscreen of the PCB. The line of the body / silkscreen resembles the cathode of the diode.

With the diode in place, I like to bend the legs so that it stays in place and I can "rinse and repeat" for the remaining diodes

<p align = "left">
    
</p>

<p align = "left">
    
</p>

After we put all the diodes in their pads, solder them, and clip the excess.

**NOTE:** You can save the diode leg clippings and use them as socket male header pins for the uC

<p align = "left">
    
</p>

<p align = "left">
    
</p>

You've now put all your diodes on the board

## uC Socket

The uC socket is pretty straight forward. We're going to place the socket pins through the pads from the bottom side of the board. 

In order to ensure that the socket doesn't fall off before we get a chance to solder it to the board, I like to use tape to hold the part in place until we solder at least one pin.

Line up the socket so that it's as straight vertically as possible and use tape to hold the socket in place.

<p align = "left">
    
</p>
<p align = "left">
    
</p>

###

Solder the pins from the top side of the board.

<p align = "left">
    
</p>

You'll notice that the socket pins get pretty close to where the first two switches mount onto the board. To avoid possible fitment issues, we're going to clip pins 24 and 20 from the top side.

<p align = "left">
    
</p>

### Hardware Fix - Tying Pin 9 to Pin 4

On the schematic I didn't catch that our CLD1 pin is tied to pin 4 on the uC, which is a ground pin (shoutout to @Josh\_little  for catching this error.) Luckily, this is a pretty easy fix. I can't show pictures of how I would recommend fixing this, because by the time this issue was found, I had already mounted the switches and the acrylic was covering where I needed to solder. Below is the pin numbering scheme for reference

<p align = "left">
    
</p>

#### Recommended Fix - Top Layer

You'll need to solder a piece of wire that connects pin 4 to pin 9 on the top side of the board. The consequence is that this will be visible through the acrylic, so you'll want to do as clean of a job as you can.

<p align = "left">
    
</p>

#### How I did it - Bottom layer underneath socket

I was forced to do the fix this way but I do not recommend doing this if you're new to soldering. You'll notice in the picture that I burned the plastic of the socket. It's not very easy. I took a piece of 30AWG wire ~ 1 inch long and stripped one end so that a little piece of wire was exposed. I tacked that end to pin 4. I then put solder on my tip, held the wire close to pin 9 and burned through the insulation until a solder connection was made. You must be careful not to have too much solder and short and pins together. I then wiggled the excess wire lightly until it snapped off

<p align = "left">
    
</p>

## uC header pins

With the socket soldered in, I put the mill-max machine header pins into the sockets. You want the pins decently in the sockets, this will be how the uC is mounted at the conclusion of this step.

**NOTE:** DO NOT POPULATE PIN 4. THAT WILL UNDO THE HARDWARE FIX DESCRIBED ABOVE. The pictures below will show pin 4 being populated,after the bug was found the pin was removed but the pictures had already been taken and I only had one board to assemble to show these steps. This is also where you could use diode legs if you don't have the Mill-Max header pins.

<p align = "left">
    
</p>

Next place your uC onto the pins

<p align = "left">
    
</p>

Solder the pins to the uC. Try not to use so much solder such that you end up soldering the uC to the socket .

<p align = "left">
    
</p>

Once cooled, you can now remove and replace your uC during debug / assembly.

##

## Stabilizers

The stabilizers need to clip into the switch plate before you begin soldering the switches. Whether you decide to go with screw in or clip in - The keyboard supports both options so that is possible. This cannot be stressed enough, if you have screw in stabilizers and plate mount switches: the stabilizers mount to the PCB and **MUST BE INSTALLED FIRST BEFORE ANY SWITCHES.**

### Assembling Stabilizers

This is a fairly straightforward process, There are three major components to stabilizers: housing, stem, and wire. Assemble the housing, insert the stem into the housing from the bottom, and then feed the wire between the housing and the stem.

NOTE: There is a sweet spot here, it may take a couple of attempts to get it right, just pop the wire from the housing and retry.

<p align = "left">
    
</p>

<p align = "left">
    
</p>

Side Note: It is common for people to modify their stabilizers. There are two common mods you can do. The first is clipping the stems. On the bottom of the stem there is an excess of plastic, clip them and you're good. The second modification is lube, apply lube to the inside of the housing and the stem where there is motion. On the bent ends of the wire, it's common for people to apply heavy lube or a type of lube called "dielectric grease", it is not necessary but does make a difference. There are endless mods to stabilizers, check out the assembly [source](https://www.keyboard.university/guides/using-screw-in-stabilizers-7nxj6) as well as a clipping [tutorial](https://switchandclick.com/how-to-mod-your-stabilizers-band-aid-clip-and-lube/).

## Switches

Note: the following pictures do not show stabilizers. This is because circuit-dude didn't realize he needed them. He installed all of his switches, bought PCB mount stabilizers after the fact, and then had to un-solder all 67 switches in order to install the stabilizers. Don't be like circuit-dude.

The switches can be a challenge while you're getting the first couple in. I found that putting in 3 switches in a triangular pattern helped keep everything relatively where it needed to be.

You're going to place the switches through the holes in the acrylic and then solder the switch to the board. Note that you need to take off the acrylic wrap prior to doing this.

<p align = "left">
    
</p>

You want the switches to sit as flush as possible to the acrylic.

<p align = "left">
    
</p>

Fill in all the holes, solder in all the switches, and bloom blam bow you damn near got a keyboard brother.

## OLED

The OLED is pretty straight forward. Solder the header pins through the holes and then onto the board. It only fits one way. Just remember to be conscious of the heat and not fry the OLED.

<p align = "left">
    
</p>

## Demultiplexer

The demultiplexer is the only SMD part on this board. It is a little challenging due to the pin pitch but it's doable. You do need to be careful not to heat up the pads too much so that they don't delaminate and rip off the board.

I'd start with "tinning" one pad (i.e. add solder to one pad on one corner).

<p align = "left">
    
</p>

With a corner tinned, use some tweezers to grab the IC. Prepare to move the IC onto that pad. We're going to melt the solder on the pad you just tinned and line up all the pins with their respective pads. You can melt the solder a couple of times if you don't get it right on the first shot.

**NOTE:** The long line on the silkscreen indicates Pin 1's position. Pin one is marked with the dot on the package of the IC.

<p align = "left">
    
</p>

<p align = "left">
    
</p>

With one corner tacked down and all the pins lined up, I like to tack a pin on the opposite corner. This makes it so the part doesn't move around while you solder the next couple pins.

<p align = "left">
    
</p>

Note the massive solder blob in the picture above. I'd recommend cleaning that up to avoid shorting pins while soldering the pins immediately to the right.

Proceed to solder the rest of the pins in whatever way you feel comfortable.

## Rotary Encoder

```diff
- I would put the rotary encoder on last because of its height.
```

The rotary encoder is pretty straight forward. Put the pins through the holes, solder the pins to the pads, bada-bing you've got a rotary encoder knob on your board. I don't have any images of installing this :'(

VOILA, you've assembled your keyboard!.

###

### Soldering Sanity Check

There is a simple program in Firmware/PCB\_sanity\_check.py that will set up all the pins associated with the matrix and then indefinitely scan the matrix and tell you which buttons were registered as pressed. You can run this code after you install circuit-python and make sure that all of your switches register when you depress them. If they don't, things to check would be:

- Demultiplexer soldering
- Switch soldering
- Socket soldering
  - Ensure that pin 4 is not populated on the uC
  - Check that pin 4 of the socket is connected to pin 9 of the socket
  - Socket connections to PCB
- Burnt traces / ripped pads
  - This would kinda suck but is fixable, it would require soldering wires from the disconnected part(s) to somewhere else that on the net that is connected.

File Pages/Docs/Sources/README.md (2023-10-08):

# List of Sources

- Design based on the Dissatisfaction 65 by [Nicell](https://github.com/Nicell/Dissatisfaction-65) 
    - PCB, Kicad Files, DXF files
- [KMK firmware](http://kmkfw.io/)

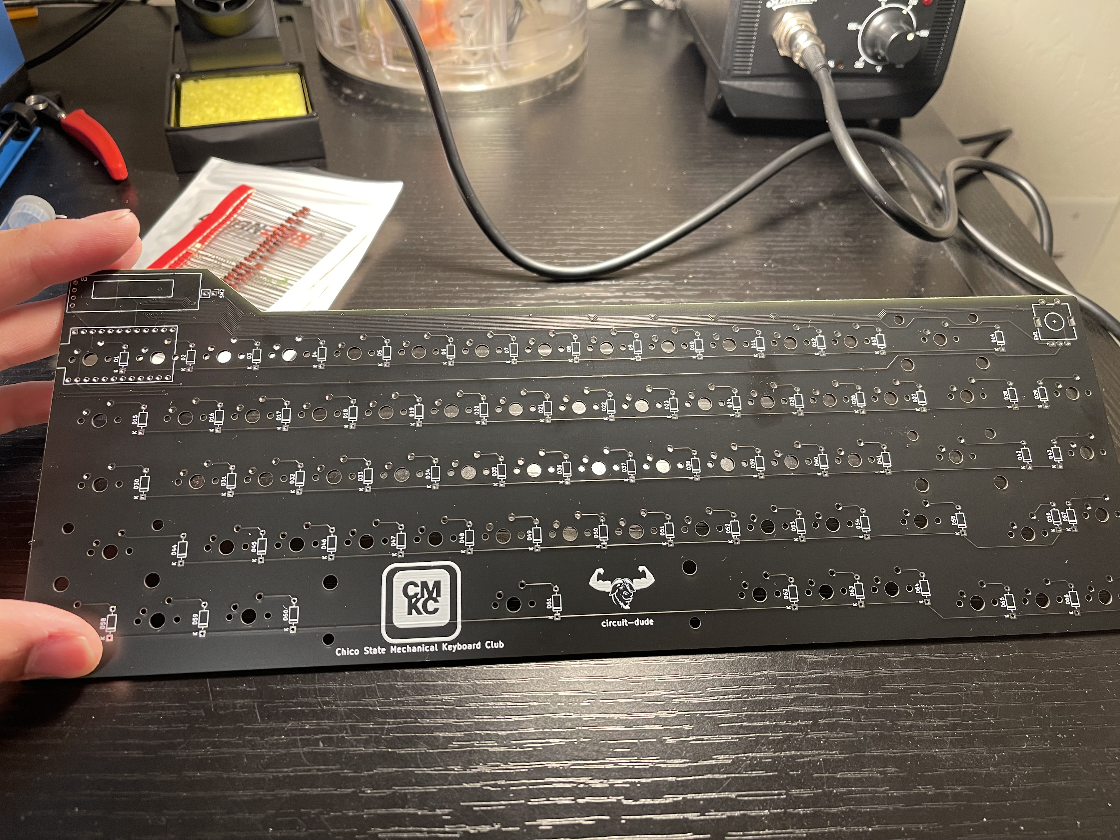
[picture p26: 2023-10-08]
Pages/Docs/Images/pcb.jpg

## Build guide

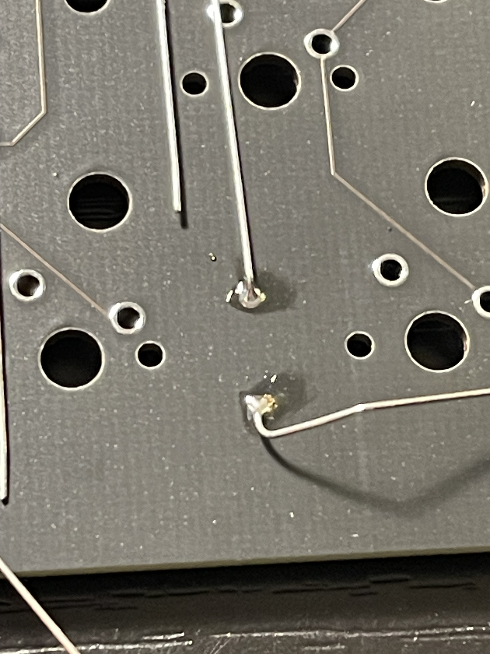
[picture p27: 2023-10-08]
Pages/Docs/Images/solder-diodes.jpg

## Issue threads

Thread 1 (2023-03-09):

Checklist

thomasdevine01, 2023-03-09:
Hardware TODO:
-Hijack keyboard matrix grid
-Confirm Placement of Nice! Nano
-Reassess OLED Screen
-Reassess Rotary Encoder
-Hijack on/off switch with reset button

Software TODO:
-Firmware Build/ Python Script
-Confirm Build with Keyboard Layout Editor
-ZMK supports bluetooth mainly, need to confirm reliability of USB C

Closed 2023-10-07.

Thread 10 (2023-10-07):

[HARDWARE] Clip socket pins that are within the body area of the switches on the top side of the PCB

Circuit-Dude, 2023-10-07:
There are some pins from the socket that can interfere with the switch bodies on the top side of the PCB.

These need to be clipped

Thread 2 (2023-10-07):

OLED Screen Support

thomasdevine01, 2023-10-07:
There is not currently software support for the OLED Screen. Need to create a prototype to get the following features implemented:

- Text Support
- Picture Support
- Macro Support?

Explore the library for the font for the OLED. There are a couple caveats as the Nice! Nano does not have a lot of free space for images.

If the library does not work Circuit-Dude has created a prototype font for the bitmap. Refine and implement

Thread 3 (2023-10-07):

Middle Plate .dxf - include cutout for USB

Circuit-Dude, 2023-10-07:
We need a modified middle plate .dxf that includes the USB cut out. The hole I used is ~ 14.8mm from the outer out edge (top left corner edge) and 19mm wide. This should be big enough to accommodate wide USB cables.

there should be at least 2 middle plates with the cut used when assembling, 3 would allow bigger USB cables to fit

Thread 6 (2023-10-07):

Convert Current Soldering Doc to Github Pages

thomasdevine01, 2023-10-07:
Add documentation in the form of a google doc to MD. I want to try to convert to github pages to make the document easy to access.

thomasdevine01, 2023-10-08:
successfully converted to github pages, included all files as MD and used the Just-The-Docs Theme

Closed 2023-10-08.

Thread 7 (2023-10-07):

Accessing the bootloader after assembly

Circuit-Dude, 2023-10-07:
TL;DR
  add hole to bottom plate
  find proper button to fit on existing pads

In order to access the bootloader, should it need to be updated or changed after assembly, we need to add a hole to the bottom plate .dxf OR drill into the bottom plate while the paper adhesive is still on the plate.

We also need a button to solder onto the "sw2" pads on the bottom side of the board. I used the ones in the link but they don't actually fit. I had to do some ghetto bending of the pins.

https://www.amazon.com/dp/B07VSNN9S2

Circuit-Dude, 2023-10-07:
This may only be necessary during active development.

Can make hole big enough for standard pair of tweezers or change footprint / part to a standard 6mm^2 momentary push button

Circuit-Dude, 2023-10-10:
foot print has been changed on the layout. a standard 6mm^2 pushbutton should fit onto / into the pads

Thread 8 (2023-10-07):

HARDWARE: pin 4 to pin 9 on the uC

Circuit-Dude, 2023-10-07:
either spin the PCB to fix layout

OR

Solder wire from pin 4 to pin 9 at the socket on the top side of the board. Do not populate pin 4 on the uC

Circuit-Dude, 2023-10-10:
New layout generated. Resolved issue in layout

Closed 2023-10-10.

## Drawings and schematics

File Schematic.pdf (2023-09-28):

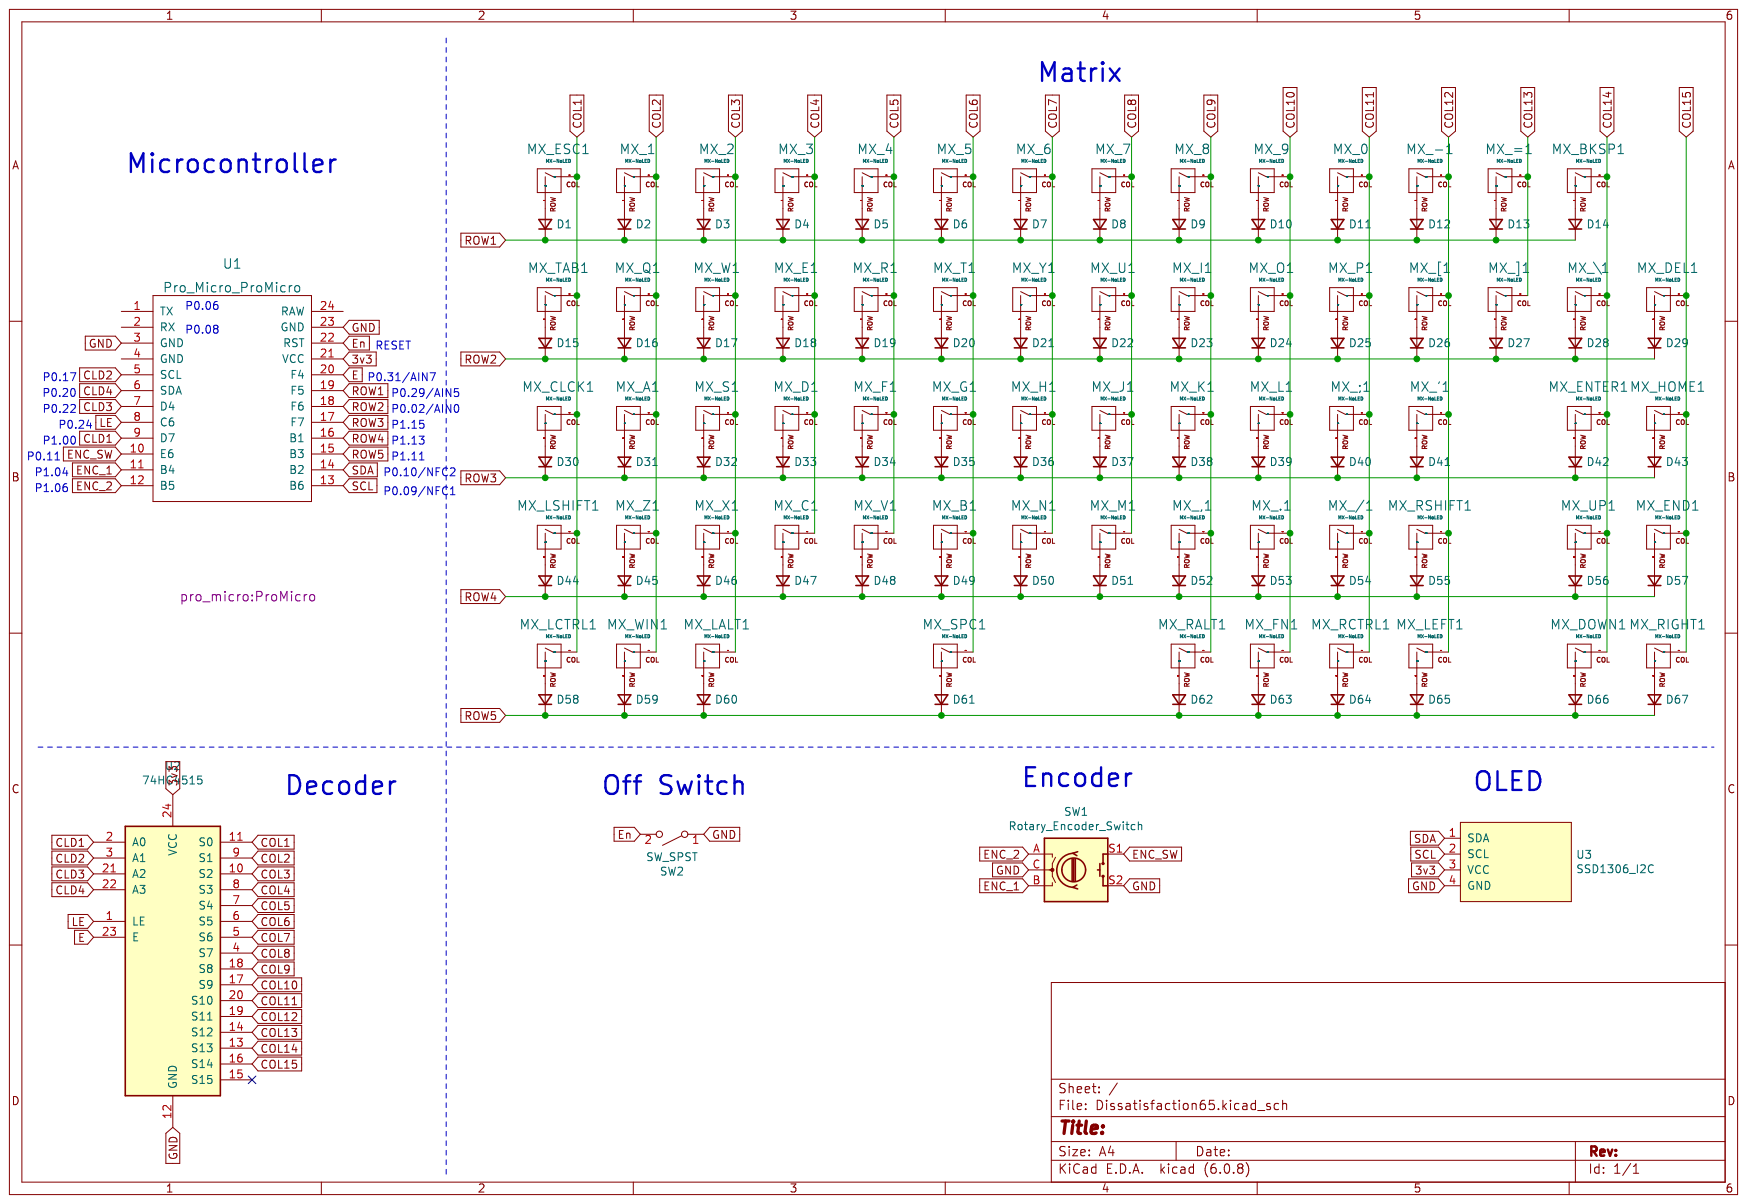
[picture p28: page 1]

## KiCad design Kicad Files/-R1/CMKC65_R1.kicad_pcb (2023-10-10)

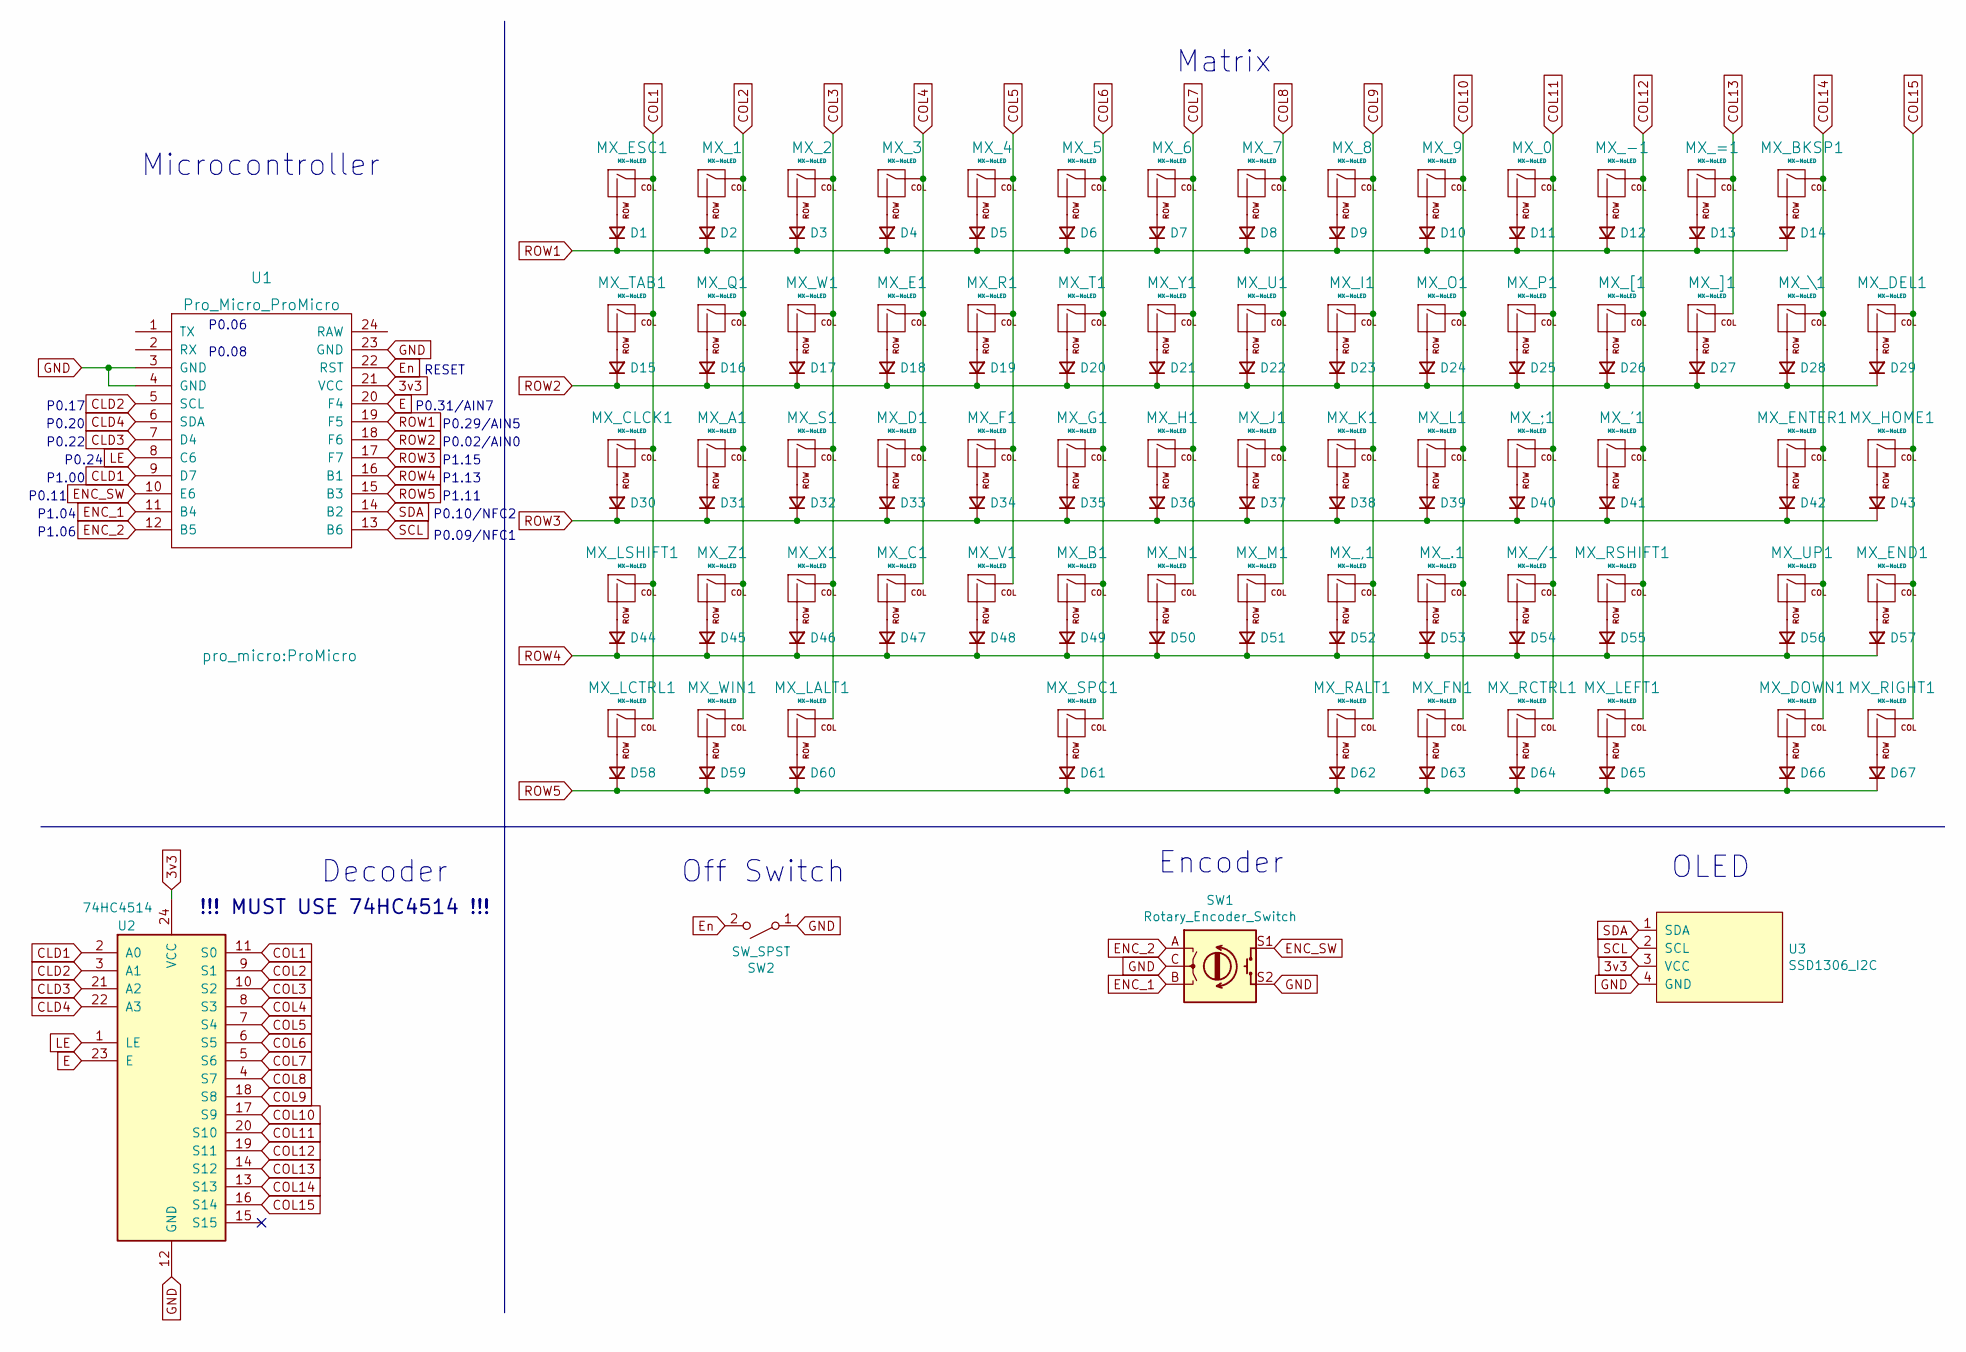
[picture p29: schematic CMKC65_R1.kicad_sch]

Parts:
D1, D2, D3, D4, D5, D6, D7, D8, D9, D10, D11, D12, D13, D14, D15, D16, D17, D18, D19, D20, D21, D22, D23, D24, D25, D26, D27, D28, D29, D30, D31, D32, D33, D34, D35, D36, D37, D38, D39, D40, D41, D42, D43, D44, D45, D46, D47, D48, D49, D50, D51, D52, D53, D54, D55, D56, D57, D58, D59, D60, D61, D62, D63, D64, D65, D66, D67: D_Small; D_DO-35_SOD27_P7.62mm_Horizontal
MX_0, MX_1, MX_2, MX_3, MX_4, MX_5, MX_6, MX_7, MX_8, MX_9, MX_.1: MX-NoLED; MXOnly-1U-NoLED
MX_'1: MX-NoLED; MXOnly-1U-NoLED
MX_,1: MX-NoLED; MXOnly-1U-NoLED
MX_-1: MX-NoLED; MXOnly-1U-NoLED
MX_/1: MX-NoLED; MXOnly-1U-NoLED
MX_;1: MX-NoLED; MXOnly-1U-NoLED
MX_=1: MX-NoLED; MXOnly-1U-NoLED
MX_A1: MX-NoLED; MXOnly-1U-NoLED
MX_B1: MX-NoLED; MXOnly-1U-NoLED
MX_BKSP1: MX-NoLED; MXOnly-2U-NoLED
MX_C1: MX-NoLED; MXOnly-1U-NoLED
MX_CLCK1: MX-NoLED; MXOnly-1.75U-NoLED
MX_D1: MX-NoLED; MXOnly-1U-NoLED
MX_DEL1: MX-NoLED; MXOnly-1U-NoLED
MX_DOWN1: MX-NoLED; MXOnly-1U-NoLED
MX_E1: MX-NoLED; MXOnly-1U-NoLED
MX_END1: MX-NoLED; MXOnly-1U-NoLED
MX_ENTER1: MX-NoLED; MXOnly-2.25U-NoLED
MX_ESC1: MX-NoLED; MXOnly-1U-NoLED
MX_F1: MX-NoLED; MXOnly-1U-NoLED
MX_FN1: MX-NoLED; MXOnly-1U-NoLED
MX_G1: MX-NoLED; MXOnly-1U-NoLED
MX_H1: MX-NoLED; MXOnly-1U-NoLED
MX_HOME1: MX-NoLED; MXOnly-1U-NoLED
MX_I1: MX-NoLED; MXOnly-1U-NoLED
MX_J1: MX-NoLED; MXOnly-1U-NoLED
MX_K1: MX-NoLED; MXOnly-1U-NoLED
MX_L1: MX-NoLED; MXOnly-1U-NoLED
MX_LALT1: MX-NoLED; MXOnly-1.25U-NoLED
MX_LCTRL1: MX-NoLED; MXOnly-1.25U-NoLED
MX_LEFT1: MX-NoLED; MXOnly-1U-NoLED
MX_LSHIFT1: MX-NoLED; MXOnly-2.25U-NoLED
MX_M1: MX-NoLED; MXOnly-1U-NoLED
MX_N1: MX-NoLED; MXOnly-1U-NoLED
MX_O1: MX-NoLED; MXOnly-1U-NoLED
MX_P1: MX-NoLED; MXOnly-1U-NoLED
MX_Q1: MX-NoLED; MXOnly-1U-NoLED
MX_R1: MX-NoLED; MXOnly-1U-NoLED
MX_RALT1: MX-NoLED; MXOnly-1U-NoLED
MX_RCTRL1: MX-NoLED; MXOnly-1U-NoLED
MX_RIGHT1: MX-NoLED; MXOnly-1U-NoLED
MX_RSHIFT1: MX-NoLED; MXOnly-1.75U-NoLED
MX_S1: MX-NoLED; MXOnly-1U-NoLED
MX_SPC1: MX-NoLED; MXOnly-6.25U-ReversedStabilizers-NoLED
MX_T1: MX-NoLED; MXOnly-1U-NoLED
MX_TAB1: MX-NoLED; MXOnly-1.5U-NoLED
MX_U1: MX-NoLED; MXOnly-1U-NoLED
MX_UP1: MX-NoLED; MXOnly-1U-NoLED
MX_V1: MX-NoLED; MXOnly-1U-NoLED
MX_W1: MX-NoLED; MXOnly-1U-NoLED
MX_WIN1: MX-NoLED; MXOnly-1.25U-NoLED
MX_X1: MX-NoLED; MXOnly-1U-NoLED
MX_Y1: MX-NoLED; MXOnly-1U-NoLED
MX_Z1: MX-NoLED; MXOnly-1U-NoLED
MX_[1: MX-NoLED; MXOnly-1U-NoLED
MX_\1: MX-NoLED; MXOnly-1.5U-NoLED
MX_]1: MX-NoLED; MXOnly-1U-NoLED
SW1: Rotary_Encoder_Switch; RotaryEncoder_Alps_EC11E-Switch_Vertical_H20mm
SW2: SW_SPST; SW_PUSH_6mm
U1: Pro_Micro_ProMicro; ProMicro
U2: 74HC4514; SOIC-24W_7.5x15.4mm_P1.27mm
U3: SSD1306_I2C; OLED

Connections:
3v3: U1.21 (VCC), U2.24 (VCC), U3.3 (VCC)
CLD1: U1.9 (D7), U2.2 (A0)
CLD2: U1.5 (SCL), U2.3 (A1)
CLD3: U1.7 (D4), U2.21 (A2)
CLD4: U1.6 (SDA), U2.22 (A3)
COL1: MX_CLCK1.1 (COL), MX_ESC1.1 (COL), MX_LCTRL1.1 (COL), MX_LSHIFT1.1 (COL), MX_TAB1.1 (COL), U2.11 (S0)
COL2: MX_1.1 (COL), MX_A1.1 (COL), MX_Q1.1 (COL), MX_WIN1.1 (COL), MX_Z1.1 (COL), U2.9 (S1)
COL3: MX_2.1 (COL), MX_LALT1.1 (COL), MX_S1.1 (COL), MX_W1.1 (COL), MX_X1.1 (COL), U2.10 (S2)
COL4: MX_3.1 (COL), MX_C1.1 (COL), MX_D1.1 (COL), MX_E1.1 (COL), U2.8 (S3)
COL5: MX_4.1 (COL), MX_F1.1 (COL), MX_R1.1 (COL), MX_V1.1 (COL), U2.7 (S4)
COL6: MX_5.1 (COL), MX_B1.1 (COL), MX_G1.1 (COL), MX_SPC1.1 (COL), MX_T1.1 (COL), U2.6 (S5)
COL7: MX_6.1 (COL), MX_H1.1 (COL), MX_N1.1 (COL), MX_Y1.1 (COL), U2.5 (S6)
COL8: MX_7.1 (COL), MX_J1.1 (COL), MX_M1.1 (COL), MX_U1.1 (COL), U2.4 (S7)
COL9: MX_8.1 (COL), MX_,1.1 (COL), MX_I1.1 (COL), MX_K1.1 (COL), MX_RALT1.1 (COL), U2.18 (S8)
COL10: MX_9.1 (COL), MX_.1.1 (COL), MX_FN1.1 (COL), MX_L1.1 (COL), MX_O1.1 (COL), U2.17 (S9)
COL11: MX_0.1 (COL), MX_/1.1 (COL), MX_;1.1 (COL), MX_P1.1 (COL), MX_RCTRL1.1 (COL), U2.20 (S10)
COL12: MX_'1.1 (COL), MX_-1.1 (COL), MX_LEFT1.1 (COL), MX_RSHIFT1.1 (COL), MX_[1.1 (COL), U2.19 (S11)
COL13: MX_=1.1 (COL), MX_]1.1 (COL), U2.14 (S12)
COL14: MX_BKSP1.1 (COL), MX_DOWN1.1 (COL), MX_ENTER1.1 (COL), MX_UP1.1 (COL), MX_\1.1 (COL), U2.13 (S13)
COL15: MX_DEL1.1 (COL), MX_END1.1 (COL), MX_HOME1.1 (COL), MX_RIGHT1.1 (COL), U2.16 (S14)
E: U1.20 (F4), U2.23 (E)
ENC_1: SW1.B, U1.11 (B4)
ENC_2: SW1.A, U1.12 (B5)
ENC_SW: SW1.S1, U1.10 (E6)
En: SW2.2 (B), U1.22 (RST)
GND: SW1.C, SW1.S2, SW2.1 (A), U1.3 (GND), U1.4 (GND), U1.23 (GND), U2.12 (GND), U3.4 (GND)
LE: U1.8 (C6), U2.1 (LE)
unnamed: D1.2 (A), MX_ESC1.2 (ROW)
unnamed: D2.2 (A), MX_1.2 (ROW)
unnamed: D3.2 (A), MX_2.2 (ROW)
unnamed: D4.2 (A), MX_3.2 (ROW)
unnamed: D5.2 (A), MX_4.2 (ROW)
unnamed: D6.2 (A), MX_5.2 (ROW)
unnamed: D7.2 (A), MX_6.2 (ROW)
unnamed: D8.2 (A), MX_7.2 (ROW)
unnamed: D9.2 (A), MX_8.2 (ROW)
unnamed: D10.2 (A), MX_9.2 (ROW)
unnamed: D11.2 (A), MX_0.2 (ROW)
unnamed: D12.2 (A), MX_-1.2 (ROW)
unnamed: D13.2 (A), MX_=1.2 (ROW)
unnamed: D14.2 (A), MX_BKSP1.2 (ROW)
unnamed: D15.2 (A), MX_TAB1.2 (ROW)
unnamed: D16.2 (A), MX_Q1.2 (ROW)
unnamed: D17.2 (A), MX_W1.2 (ROW)
unnamed: D18.2 (A), MX_E1.2 (ROW)
unnamed: D19.2 (A), MX_R1.2 (ROW)
unnamed: D20.2 (A), MX_T1.2 (ROW)
unnamed: D21.2 (A), MX_Y1.2 (ROW)
unnamed: D22.2 (A), MX_U1.2 (ROW)
unnamed: D23.2 (A), MX_I1.2 (ROW)
unnamed: D24.2 (A), MX_O1.2 (ROW)
unnamed: D25.2 (A), MX_P1.2 (ROW)
unnamed: D26.2 (A), MX_[1.2 (ROW)
unnamed: D27.2 (A), MX_]1.2 (ROW)
unnamed: D28.2 (A), MX_\1.2 (ROW)
unnamed: D29.2 (A), MX_DEL1.2 (ROW)
unnamed: D30.2 (A), MX_CLCK1.2 (ROW)
unnamed: D31.2 (A), MX_A1.2 (ROW)
unnamed: D32.2 (A), MX_S1.2 (ROW)
unnamed: D33.2 (A), MX_D1.2 (ROW)
unnamed: D34.2 (A), MX_F1.2 (ROW)
unnamed: D35.2 (A), MX_G1.2 (ROW)
unnamed: D36.2 (A), MX_H1.2 (ROW)
unnamed: D37.2 (A), MX_J1.2 (ROW)
unnamed: D38.2 (A), MX_K1.2 (ROW)
unnamed: D39.2 (A), MX_L1.2 (ROW)
unnamed: D40.2 (A), MX_;1.2 (ROW)
unnamed: D41.2 (A), MX_'1.2 (ROW)
unnamed: D42.2 (A), MX_ENTER1.2 (ROW)
unnamed: D43.2 (A), MX_HOME1.2 (ROW)
unnamed: D44.2 (A), MX_LSHIFT1.2 (ROW)
unnamed: D45.2 (A), MX_Z1.2 (ROW)
unnamed: D46.2 (A), MX_X1.2 (ROW)
unnamed: D47.2 (A), MX_C1.2 (ROW)
unnamed: D48.2 (A), MX_V1.2 (ROW)
unnamed: D49.2 (A), MX_B1.2 (ROW)
unnamed: D50.2 (A), MX_N1.2 (ROW)
unnamed: D51.2 (A), MX_M1.2 (ROW)
unnamed: D52.2 (A), MX_,1.2 (ROW)
unnamed: D53.2 (A), MX_.1.2 (ROW)
unnamed: D54.2 (A), MX_/1.2 (ROW)
unnamed: D55.2 (A), MX_RSHIFT1.2 (ROW)
unnamed: D56.2 (A), MX_UP1.2 (ROW)
unnamed: D57.2 (A), MX_END1.2 (ROW)
unnamed: D58.2 (A), MX_LCTRL1.2 (ROW)
unnamed: D59.2 (A), MX_WIN1.2 (ROW)
unnamed: D60.2 (A), MX_LALT1.2 (ROW)
unnamed: D61.2 (A), MX_SPC1.2 (ROW)
unnamed: D62.2 (A), MX_RALT1.2 (ROW)
unnamed: D63.2 (A), MX_FN1.2 (ROW)
unnamed: D64.2 (A), MX_RCTRL1.2 (ROW)
unnamed: D65.2 (A), MX_LEFT1.2 (ROW)
unnamed: D66.2 (A), MX_DOWN1.2 (ROW)
unnamed: D67.2 (A), MX_RIGHT1.2 (ROW)
ROW1: D1.1 (K), D2.1 (K), D3.1 (K), D4.1 (K), D5.1 (K), D6.1 (K), D7.1 (K), D8.1 (K), D9.1 (K), D10.1 (K), D11.1 (K), D12.1 (K), D13.1 (K), D14.1 (K), U1.19 (F5)
ROW2: D15.1 (K), D16.1 (K), D17.1 (K), D18.1 (K), D19.1 (K), D20.1 (K), D21.1 (K), D22.1 (K), D23.1 (K), D24.1 (K), D25.1 (K), D26.1 (K), D27.1 (K), D28.1 (K), D29.1 (K), U1.18 (F6)
ROW3: D30.1 (K), D31.1 (K), D32.1 (K), D33.1 (K), D34.1 (K), D35.1 (K), D36.1 (K), D37.1 (K), D38.1 (K), D39.1 (K), D40.1 (K), D41.1 (K), D42.1 (K), D43.1 (K), U1.17 (F7)
ROW4: D44.1 (K), D45.1 (K), D46.1 (K), D47.1 (K), D48.1 (K), D49.1 (K), D50.1 (K), D51.1 (K), D52.1 (K), D53.1 (K), D54.1 (K), D55.1 (K), D56.1 (K), D57.1 (K), U1.16 (B1)
ROW5: D58.1 (K), D59.1 (K), D60.1 (K), D61.1 (K), D62.1 (K), D63.1 (K), D64.1 (K), D65.1 (K), D66.1 (K), D67.1 (K), U1.15 (B3)
SCL: U1.13 (B6), U3.2 (SCL)
SDA: U1.14 (B2), U3.1 (SDA)

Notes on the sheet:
P0.20
P0.08
P0.24
P0.29/AIN5
!!! MUST USE 74HC4514 !!!
Decoder
P1.06
P1.11
P0.31/AIN7
Microcontroller
P0.06
P0.22
Off Switch
P1.00
P0.02/AIN0
OLED
P0.10/NFC2
Matrix
P0.09/NFC1
P1.04
P0.11
RESET
Encoder
P1.13
P1.15
P0.17

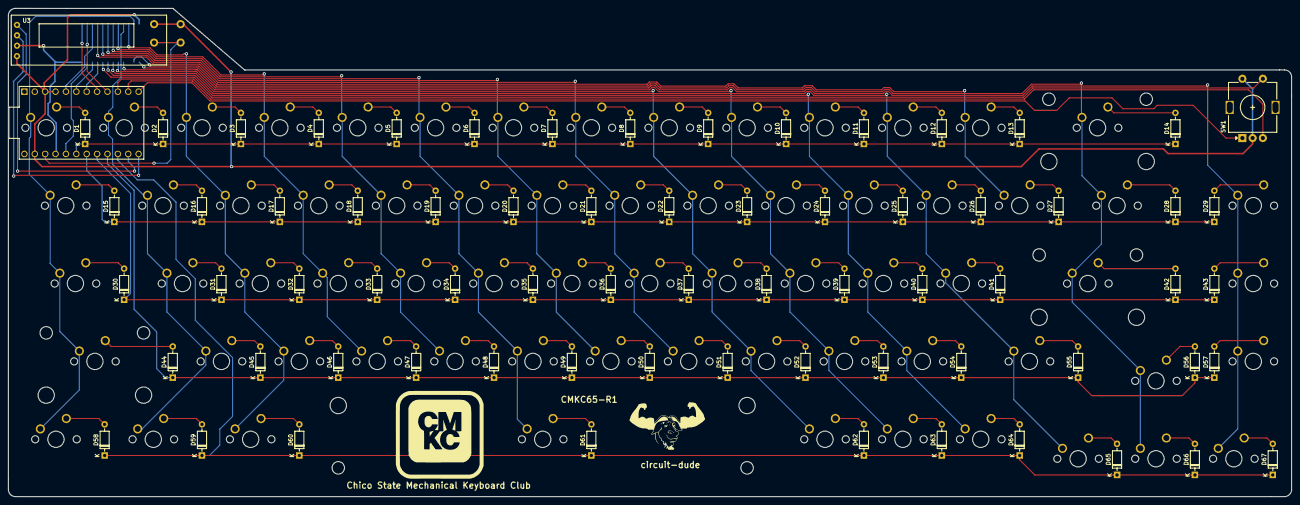
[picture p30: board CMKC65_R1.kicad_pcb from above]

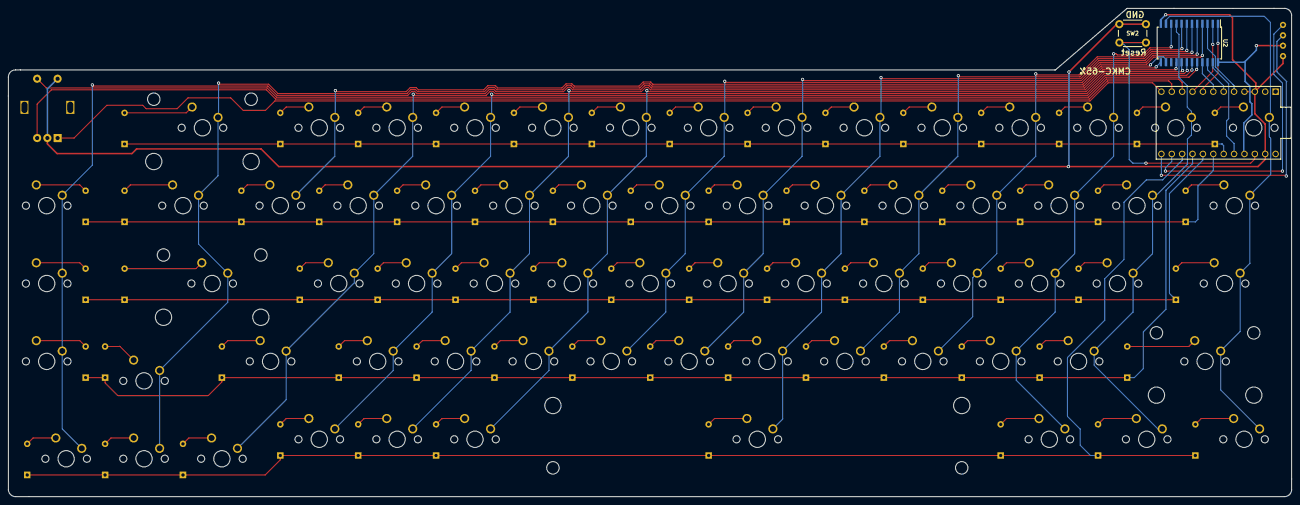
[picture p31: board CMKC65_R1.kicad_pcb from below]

Board: 2 copper layers, 313.9 x 119.4 mm, 141 parts (3 on the bottom side), 101 nets.

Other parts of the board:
Chico State Mechanical Keyboard Club: LOGO
circuit-dude: LOGO

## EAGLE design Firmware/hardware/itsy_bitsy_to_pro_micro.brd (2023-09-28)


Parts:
FRAME2: FRAME-LETTER; CREATIVE_COMMONS
JP1: HEADER-1X570MIL; 1X05_ROUND_70
JP2, JP4: HEADER-1X14; 1X14_ROUND70
JP3, JP5: M12PTH; 1X12

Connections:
!RESET: JP3.3, JP4.14
+3V3: JP4.13
A0: JP3.5, JP4.10
A1: JP3.6, JP4.9
A2: JP3.7, JP4.8
A3: JP3.8, JP4.7
A4: JP3.9, JP4.6
A5: JP3.10, JP4.5
AREF: JP4.12
D2: JP4.1
D3: JP1.4
D4: JP1.5
D5_5V: JP2.10
D7: JP2.9, JP5.1
D9: JP2.8, JP5.2
D10: JP2.7, JP5.3
D11: JP2.6, JP5.4
D12: JP2.5, JP5.5
D13: JP2.4, JP5.6
EN: JP1.1
GND: JP2.2, JP3.2, JP5.9, JP5.10
MISO: JP4.2
MOSI: JP3.12, JP4.3
RAW_PM: JP3.1
RX_D0: JP2.14, JP5.11
SCK: JP3.11, JP4.4
SCL: JP2.11, JP5.7
SDA: JP2.12, JP5.8
SWCLK: JP1.3
SWDIO: JP1.2
TX_D1: JP2.13, JP5.12
VBAT: JP2.1
VBUS: JP2.3, JP3.4
VHI: JP4.11

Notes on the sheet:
TX0/PD3->TX RX1/PD2->RX GND->GND GND->GND 2/PD1->SDA 3/PD0->SCL 4/PD4->13 5/PC6->12 6/PD7->11 7/PE6->10 8/PB4->9 9/PB5->7
OLD
Raw-> GND->GND RST->RST VCC->USB A3/PF4->A0 A2/PF5->A1 A1/PF6->A2 A0/PF7->A3 15/PB1->A4 14/PB3->A5 16/PB2->SCK 10/PB6->MOSI
Bryan Siepert



Board: 2 copper layers, 35.8 x 20.7 mm, 6 parts (2 on the bottom side), 21 nets.

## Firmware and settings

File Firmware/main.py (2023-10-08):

#==================================
# This code is meant to be a sanity check after assembling the circuits on the PCB.
# and flashing the uC. We can check that every button is "seen" when we press it.
#==================================

print("Hello World!")

import board
import digitalio
import time


from kmk.kmk_keyboard import KMKKeyboard
from kmk.keys import KC
from kmk.scanners import DiodeOrientation



#==================================
# E and LE pins
#==================================
    #LE needs to be high
    #E needs to be low
LE = digitalio.DigitalInOut(board.P0_24)
LE.direction = digitalio.Direction.OUTPUT
LE.value = 1

E = digitalio.DigitalInOut(board.P0_31)
E.direction = digitalio.Direction.OUTPUT
E.value = 0


#==================================
# Rotary Encoder push button
#==================================
SW = digitalio.DigitalInOut(board.P0_11)
SW.direction = digitalio.Direction.INPUT
SW.pull = digitalio.Pull.UP

#print(dir(board))  #shows all pins names on uC


#from kb import KMKKeyboard
keyboard = KMKKeyboard()

#keyboard.matrix = "MatrixScanner"
#keyboard.matrix = "MatrixScanner"

print("Starting")



col_pins = [
        board.P1_00,
        board.P0_17,
        board.P0_22,
        board.P0_20,
        #board.P0_31
    ]


row_pins = [
    board.P0_29,
    board.P0_02,
    board.P1_15,
    board.P1_13,
    board.P1_11,
]
keyboard.diode_orientation = DiodeOrientation.COL2ROW
keyboard.col_pins = col_pins
keyboard.row_pins = row_pins

keyboard.keymap = [
    # Base Layer
    [
        KC.ESC, KC.N1, KC.N2, KC.N3, KC.N4, KC.N5, KC.N6, KC.N7, KC.N8, KC.N9, KC.N0, KC.MINUS, KC.EQUAL, KC.BSPC, KC.NO, KC.NO,
        KC.TAB, KC.Q, KC.W, KC.E, KC.R, KC.T, KC.Y, KC.U, KC.I, KC.O, KC.P, KC.LBRACKET, KC.RBRACKET, KC.BSLASH, KC.DELETE, KC.NO,
        KC.CAPS, KC.A, KC.S, KC.D, KC.F, KC.G, KC.H, KC.J, KC.K, KC.L, KC.SCOLON, KC.QUOTE, KC.NO, KC.ENTER, KC.HOME, KC.NO,
        KC.LSHIFT, KC.Z, KC.X, KC.C, KC.V, KC.B, KC.N, KC.M, KC.COMMA, KC.DOT, KC.SLASH, KC.RSHIFT, KC.NO, KC.UP, KC.END, KC.NO, 
        KC.LCTRL, KC.LGUI, KC.LALT, KC.NO, KC.NO, KC.SPACE, KC.NO, KC.NO, KC.RALT, KC.MO(1), KC.RCTRL, KC.LEFT, KC.DOWN, KC.RIGHT, KC.NO, KC.NO,
    ],
    
    # Function Layer
    [
        KC.TILDE, KC.F1, KC.F2, KC.F3, KC.F4, KC.F5, KC.F6, KC.F7, KC.F8, KC.F9, KC.F10, KC.F11, KC.F12, KC.TRNS, KC.NO, KC.NO,
        KC.TRNS, KC.BT_PREV_CONN, KC.BT_NEXT_CONN, KC.TRNS, KC.TRNS, KC.TRNS, KC.TRNS, KC.TRNS, KC.TRNS, KC.TRNS, KC.TRNS, KC.TRNS, KC.TRNS, KC.TRNS, KC.TRNS, KC.NO,
        KC.TRNS, KC.TRNS, KC.TRNS, KC.TRNS, KC.TRNS, KC.TRNS, KC.TRNS, KC.TRNS, KC.TRNS, KC.TRNS, KC.TRNS, KC.TRNS, KC.TRNS, KC.PGUP, KC.NO,
        KC.TRNS, KC.TRNS, KC.TRNS, KC.TRNS, KC.TRNS, KC.TRNS, KC.TRNS, KC.TRNS, KC.TRNS, KC.TRNS, KC.TRNS, KC.TRNS, KC.TRNS, KC.PGDN, KC.NO, KC.NO,
        KC.TRNS, KC.TRNS, KC.TRNS, KC.TRNS, KC.TRNS, KC.TRNS, KC.TRNS, KC.TRNS, KC.TRNS, KC.TRNS, KC.NO, KC.NO, KC.NO, KC.NO, KC.NO, KC.NO,
    ],
]


print("here bottom of main.py")
if __name__ == '__main__':
    keyboard.debug = True
    keyboard.go()

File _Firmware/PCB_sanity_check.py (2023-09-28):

#==================================
# This code is meant to be a sanity check after assembling the circuits on the PCB.
# and flashing the uC. We can check that every button is "seen" when we press it.
#==================================

print("Hello World!")

import board
import digitalio
import time


from digitalio import DigitalInOut, Direction, Pull




#==================================
# E and LE pins
#==================================
    #LE needs to be high
    #E needs to be low
LE = digitalio.DigitalInOut(board.P0_24)
LE.direction = digitalio.Direction.OUTPUT
LE.value = 1

E = digitalio.DigitalInOut(board.P0_31)
E.direction = digitalio.Direction.OUTPUT
E.value = 0

#==================================
# CLD pins
#==================================
CLD1 = digitalio.DigitalInOut(board.P1_00)
CLD1.direction = digitalio.Direction.OUTPUT
CLD1.value = 0

CLD2 = digitalio.DigitalInOut(board.P0_17)
CLD2.direction = digitalio.Direction.OUTPUT
CLD2.value = 0

CLD3 = digitalio.DigitalInOut(board.P0_22)
CLD3.direction = digitalio.Direction.OUTPUT
CLD3.value = 0

CLD4 = digitalio.DigitalInOut(board.P0_20)
CLD4.direction = digitalio.Direction.OUTPUT
CLD4.value = 0

#==================================
# ROW pins
#==================================
ROW1 = digitalio.DigitalInOut(board.P0_29)
ROW1.direction = digitalio.Direction.INPUT
ROW1.pull = Pull.DOWN

ROW2 = digitalio.DigitalInOut(board.P0_02)
ROW2.direction = digitalio.Direction.INPUT
ROW2.pull = Pull.DOWN

ROW3 = digitalio.DigitalInOut(board.P1_15)
ROW3.direction = digitalio.Direction.INPUT
ROW3.pull = Pull.DOWN

ROW4 = digitalio.DigitalInOut(board.P1_13)
ROW4.direction = digitalio.Direction.INPUT
ROW4.pull = Pull.DOWN

ROW5 = digitalio.DigitalInOut(board.P1_11)
ROW5.direction = digitalio.Direction.INPUT
ROW5.pull = Pull.DOWN


print(dir(board))  #shows all pins names on uC


cols = [CLD1, CLD2, CLD3, CLD4]
rows = [ROW1, ROW2, ROW3, ROW4, ROW5]


#reset columns
for i in range(3):
    cols[i].value = 0
    print("i is", i)
    




while True:

# this looks stupid, but we need to toggle every "bit" in our "cols" variable so that we can count from 0-14 in binary.
# State machine looks like: select column, check all rows, tell us which button is pressed based on col,row 
    for d in range(2): #bit 3
        cols[3].value = d
        for c in range(2): #bit 2
            cols[2].value = c
            for b in range(2): #bit 1
                cols[1].value = b
                for a in range(2): #bit 0
                    cols[0].value = a
                    for j in range(5):
                        if rows[j].value:
                            col = ((8*d) + (4*c) + (2*b )+ a)
                            print("Button column: ", col, ", row: ", j, " pressed")
                            time.sleep(0.1)

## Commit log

2023-03-09 Adding work done to import NICE!-nano
    This is the work done to modify the existing 65% mechanical keyboard design from Nicell/Dissatisfaction-65.
    Not exactly sure what needs to be added in order for the project to work correctly, hopefully all the libraries aren't broken after this commit.
    Work done includes:
    - schematic changes to support NICE!-nano uC - pin selections we're chosen at random. changing pin selections may lead to an easier time routing but this was mostly for a first pass/sanity check when linking the footprint.
    -Note on the footprint, the footprint was leveraged from an existing design, mkdl/Unix60. The footprint was saved from the project's PCB and added to a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
    [Dissatisfaction65.kicad_pcb, Dissatisfaction65.kicad_sch, Dissatisfaction65.sch]
2023-03-13 Placed NICE!-nano such that the micro usb comes right up to the edge of the board re-routed a bunch of column signals, the rotary encoder signals, reset switch, rotary encoder push button switch, 3v3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
    [Dissatisfaction65.kicad_pcb, Dissatisfaction65.kicad_sch]
2023-03-20 adding gerbers
    [Dissatisfaction65-B_Cu.gbl, Dissatisfaction65-B_Mask.gbs, Dissatisfaction65-B_Paste.gbp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]
2023-05-07 updated readme to contain framework for guide
2023-09-28 Removed submodule from 'firmware'
    [itsy_bitsy_to_pro_micro.brd, itsy_bitsy_to_pro_micro.sch, kmkpython_ref.tsv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]
2023-09-28 adding some sanity check code to the firmware repo. The essentially performs a keyboard matrix scan and prints back to the user which button was pressed in terms of rows and columns.
    This is meant to allow people to check that everything is working correctly after PCB assembly and flashing the board. If you can't hit every key on your keyboard and see the correct button press (or anything at all) on the serial console, something broke
    [PCB_sanity_check.py]
2023-09-28 adding schematic pdf for people without KiCad
    I also changed the scheamtic to reflect the known hardware issue where CLD1 was connected to PIN4. PIN4 is a straight up GND pin on the uC. So far this addresses the issues with the schematic. LAYOUT HAS NOT BEEN UPDATED YET. This is a @todo before doing another run of PCBs.
2023-09-28 Moved Kicad files from root to separate folder
    [Dissatisfaction65.kicad_pcb, Dissatisfaction65.kicad_sch, Dissatisfaction65.sch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]
2023-09-30 Adding updated schematic. This is the scheamtic I used to generate the pdf with an addition bold comment by the decoder that we must use the 74HC4514
    [Dissatisfaction65.kicad_sch]
2023-10-08 Table of contents added to assembly guide
2023-10-08 added pictures to assembly guide readme
2023-10-08 Added main.py, kmk_keyboard.py and tidied Firmware/ Folder
    [pyvenv.cfg]
2023-10-08 Github pages setup and deployment
    sources
    Update README.md
    added icon
    Update _config.yml
    renamed files
    dark mode testing
    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
    [Dissatisfaction65-B_Cu.gbl, Dissatisfaction65-B_Mask.gbs, Dissatisfaction65-B_Paste.gbp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]
2023-10-08 separated pages content
    [Dissatisfaction65-B_Cu.gbl, Dissatisfaction65-B_Mask.gbs, Dissatisfaction65-B_Paste.gbp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]
2023-10-10 Restructured Kicad Files Directory
    Added new -R1 folder. I'm not sure how we want to archive but this is how I'm used to.
    Deleted a bunch of bloat
    updated layout to fix the pin 4 - pin 9 problem on the uC socket.
    Added different reset switch, 6mm x 6mm push buttons are much more common
    added reset and gnd silkscreen for people who don't install a pushbutton for reset
    added CMKC-65% silkscreen to top side of board by OLED. This should be visible in the corner when assembled
    moved Chico State Mechanical Keyboard Club silkscreen down so that it's more visible after assembly
    added CMKC65-R1 silkscreen by the logos, this is the PCB revision number for version tracking. This should be hidden by th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
    [CMKC65_R1-B_Cu.gbl, CMKC65_R1-B_Mask.gbs, CMKC65_R1-B_Paste.gbp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]
2023-10-10 update readme for Kicad Folder
2023-10-10 update gerbers with new -R1 gerbers
    [CMKC65_R1-B_Cu.gbl, CMKC65_R1-B_Mask.gbs, CMKC65_R1-B_Paste.gbp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]
2023-10-11 removed _
    [itsy_bitsy_to_pro_micro.brd, itsy_bitsy_to_pro_micro.sch, kmkpython_ref.tsv]

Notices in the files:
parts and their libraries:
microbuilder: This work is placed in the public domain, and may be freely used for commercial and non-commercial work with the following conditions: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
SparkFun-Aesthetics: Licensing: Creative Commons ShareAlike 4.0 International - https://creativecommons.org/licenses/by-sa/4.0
